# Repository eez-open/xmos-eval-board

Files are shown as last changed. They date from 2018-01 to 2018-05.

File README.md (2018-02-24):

### Ownership and License

The contributors are listed in CONTRIB.TXT. This project uses the TAPR v1.0 license, see LICENSE.TXT.
EEZ _xmos-eval-board_ uses the [C4.1 (Collective Code Construction Contract)](http://rfc.zeromq.org/spec:22) process for contributions.
To report an issue, use the [issue tracker](https://github.com/eez-open/xmos-eval-board/issues).

### Overview

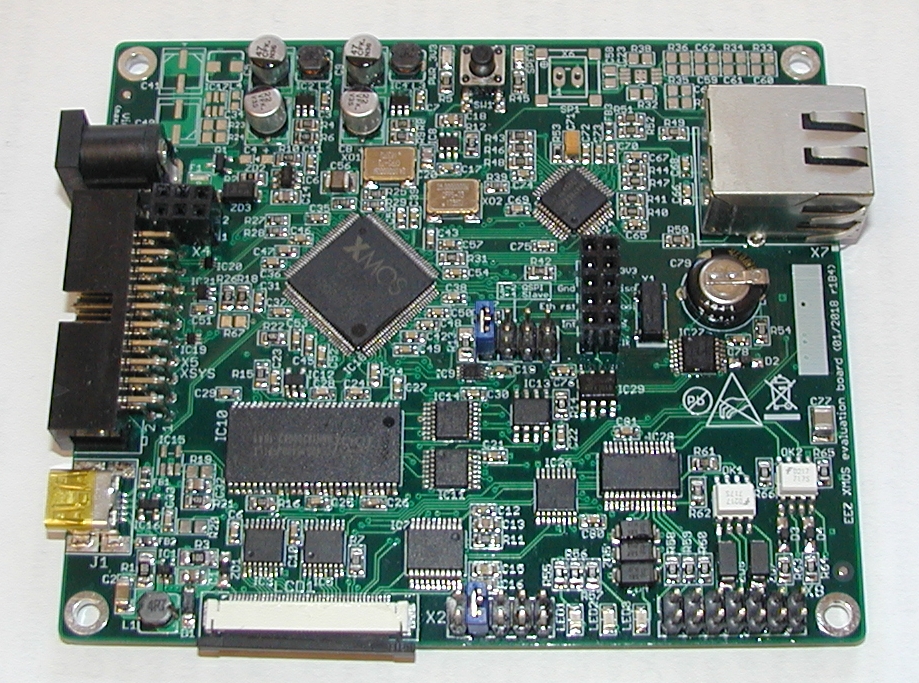
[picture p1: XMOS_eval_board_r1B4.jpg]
PCB r1B4 assembled


This project is an attempt to learn more about [XMOS xCORE-200](http://www.xmos.com/products/silicon/xcore-200) multicore microcontroller XE216-512-TQ128 by making evaluation board that would be used as a prototype or building block in some future DIY open source Test & Measurement (T&M) projects.
Selected MCU has 16 _logical_ cores divided between two hardware cores (_tiles_)and include USB 2.0 and [RGMII](https://en.wikipedia.org/wiki/Media-independent_interface) for Gigabit Ethernet. It has the highest pin count that comes in easy to mounting package (not BGA).
The evaluation board is based on XMOS evaluation boards and a couple of so-called _sliceCARDs_.

Evaluation board features:

- PCB dimension: 100 x 85 mm
- Power supply: 12 Vdc with on board regulators for 1 V, 3.3 V (sequenced) and 5 V (for USB host)
- XSYS 20-pin IDC connector for JTAG and real-time debugging (via 2-wire _xlink0_) with ESD protection
- USB AB-mini 5-pin plug with ESD protection (hopefully can be used for [OTG](https://en.wikipedia.org/wiki/USB_On-The-Go) operation)
- Support for RGB 4.3" LCD TFT (40-pin FFC 0.5 mm), 16-bit color space supported
- LCD WLED power supply with brightness control (PWM)
- Resistive touch screen controller (SPI)
- QSPI Flash memory
- 10-pin IDC connector for direct access to Flash memory
- 16-bit I/O port expander with 2 opto-isolated input, 2 opto-isolated outputs, 3 on-board LEDs, 3 TVS protected inputs
- Real time clock (SPI) with supercap backup (Vbat)
- EEPROM (SPI)
- SDRAM (multiplexed address and data bus)
- 20-pin FFC 0.5 mm socket for Riverdi LCD TFT displays (SPI, Audio out)
- Micro SD Card socket (SPI)
- 10/100 Mbit Ethernet PHY with RJ-45 socket
- Low-power audio amplifier
- 10-pin header for cheap W5500 Ethernet module (SPI)
- Reset switch

For MCU pin mapping check _[Portmap for EEZ evaluation board](XE216-512-TQ128_portmap_for_EEZ_evaluation_board_r1B4.pdf)_

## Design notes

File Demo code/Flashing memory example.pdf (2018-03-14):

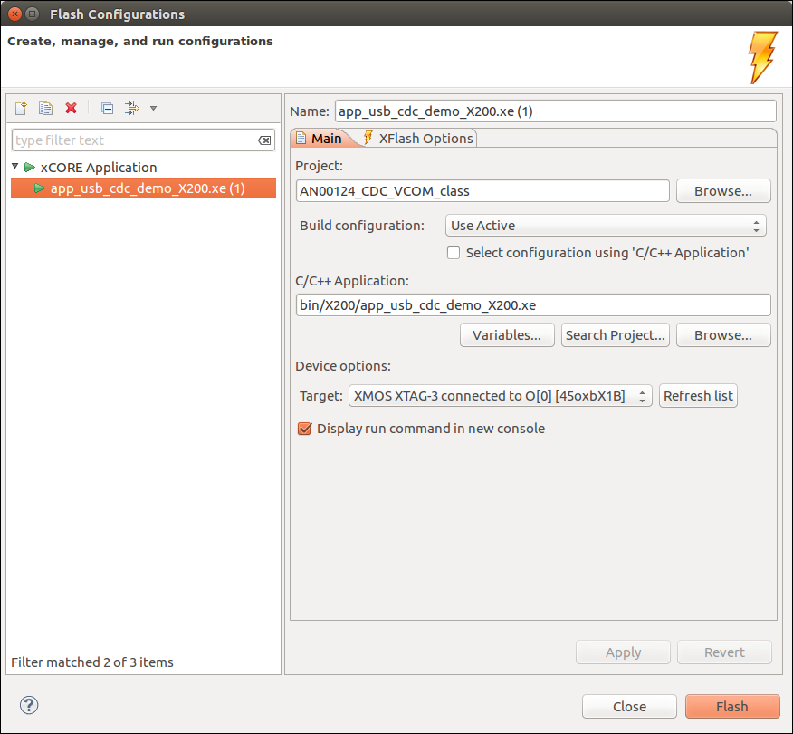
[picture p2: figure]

Adesto_AT25SF081.txt file content:

8, | /* 1. libflash device ID */
256, | /* 2. Page size */
2048, | /* 3. Number of pages */
3, | /* 4. Address size */
3, | /* 5. Clock divider */
0x9f, | /* 6. RDID cmd */
0, | /* 7. RDID dummy bytes */
3, | /* 8. RDID data size in bytes */
0x1F8501, | /* 9. RDID manufacturer ID */
0x20, | /* 10. SE cmd 0x20 */
4096, | /* 11. SE full sector erase */
0x06, | /* 12. WREN cmd 0x06 */
0x04, | /* 13. WRDI cmd 0x04 */
PROT_TYPE_SR, | /* 14. Protection type */
{{0x0 ,0x0 },{0,0}}, | /* 15. SR protect and unprotect cmds */
0x02, | /* 16. PP cmd */
0xeb, | /* 17. READ cmd */
1, | /* 18. READ dummy bytes */
SECTOR_LAYOUT_REGULAR, /* 19. Sector layout */
{4096,{0,{0}}}, | /* 20. Sector sizes */
0x05, | /* 21. RDSR cmd */
0x01, | /* 22. WRSR cmd 0x01 */
0x01, | /* 23. WIP bit mask */

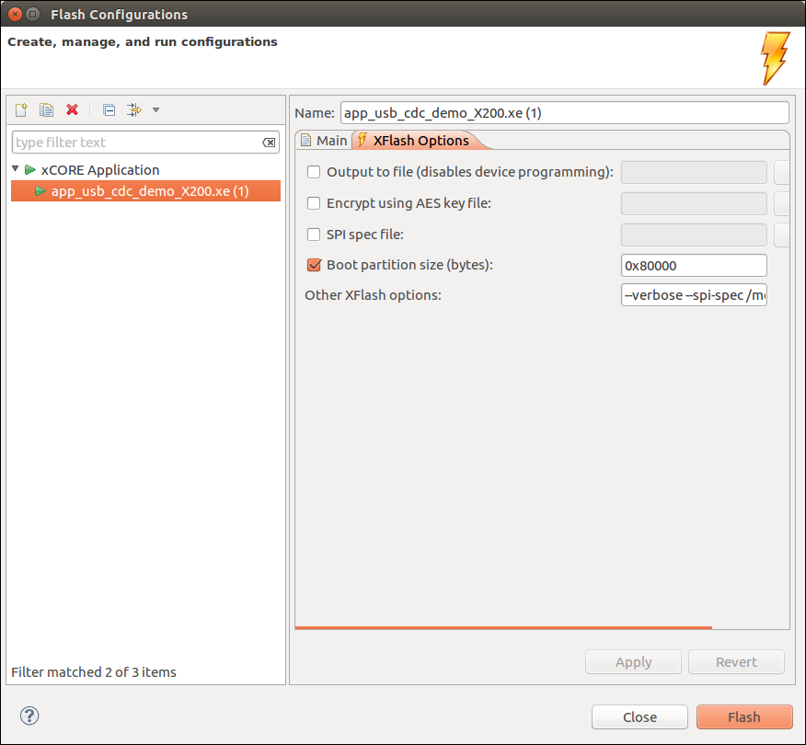
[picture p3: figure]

Other Xflash options:

--verbose --spi-spec
/media/denis/SSD_256GB/BACKUP/EEZ/XMOS/Community_14.3.2/bin/Adesto_AT25SF081.txt Flash operation results displayed in xTIMEcomposer console:

XFlash_Application found _start :40000 on Node 0
XFlash_Application found _DoSyscall :431c8 on Node 0 XFlash_Application found _DoException :400a4 on Node 0 XFlash_Application found _start :40000 on Node 0 XFlash_Application found _DoSyscall :40514 on Node 0 XFlash_Application found _DoException :400a4 on Node 0 XFlash_Application : Attempting to Compress Binary Data libcompressor marker 1=186
libcompressor marker 2=83
libcompressor marker 3=158
libcompressor best marker length 3 2 2 libcompressor best marker length 3 2 3 libcompressor best marker length 3 2 4 libcompressor best marker length 4 2 4 libcompressor best marker length 5 2 4
libcompressor best marker length 6 2 4
libcompressor DoCompression_Compress took : 216ms
libcompressor compile command=xcc -nostartfiles -Xmapper --bootstyle=forsim -x assembler-with-cpp "decompressor-3896629b" -x xn "target-xn-v0-3d1c5a34" -o decompressor-7fe0cb76 libcompressor validating decompressor decompressor-7fe0cb76 libcompressor launching simulator decompressor-7fe0cb76 --disable-syscalls --max-cycles 100000000
libcompressor simulator starting @0x40000
libcompressor simulator terminate @0x7ff58
libcompressor decompressor validated
XFlash_Application on Node : 0 compressed from : 14812 bytes to : 10432 bytes (29.57%)
libcompressor marker 1=19
libcompressor marker 2=26
libcompressor marker 3=30
libcompressor best marker length 3 2 2 libcompressor best marker length 3 2 3 libcompressor best marker length 3 2 4 libcompressor best marker length 3 2 5
libcompressor best marker length 4 2 5
libcompressor DoCompression_Compress took : 5ms
libcompressor compile command=xcc -nostartfiles -Xmapper --bootstyle=forsim -x assembler-with-cpp "decompressor-2804bf4d" -x xn "target-xn-v0-3d1c5a34" -o decompressor-c6a96ed7
libcompressor validating decompressor decompressor-c6a96ed7
libcompressor launching simulator decompressor-c6a96ed7 --disable-syscalls --max-cycles 100000000
libcompressor simulator starting @0x40000
libcompressor simulator terminate @0x7ff5a
libcompressor decompressor validated
XFlash_Application on Node : 0 compressed from : 1568 bytes to : 1308 bytes (16.58%)
XFlash::DoXFlash
XFlash::DoImageProgramming
XFlash::GetDeviceInfo
XFlash_DeviceInfo::GetDeviceInfo_Hardware XFlash_DeviceInfo::GetDeviceInfo_Hardware_IssueCompileCommand : xcc -Xmapper --dontenablesodlinks -Xmapper --wnoXN -x xc "spiinfo-1a9eb841" -x xn "target-xn-v0-3d1c5a34" -o "spiinfo-4bfe5879" -lquadflash -D xnPORT_SQI_CS0=PORT_SQI_CS -D xnPORT_SQI_SCLK0=PORT_SQI_SCLK -D xnPORT_SQI_SIO0=PORT_SQI_SIO XFlash_Utils::BuildRunCommand : xrun --io --adapter-id 45oxbX1B spiinfo-4bfe5879 Warning: F03098 XFlash::BuildFlashBinaryFile XFlash_Builder_S2L::BuildStage2Loaders Factory
Stage2_Loader::Compile : xcc -Wno-bidirectional-buffered-port -Xmapper --dontenablesodlinks -Xmapper --nochaninit -Xmapper --noinitialtidy -Xmapper --image-base -Xmapper 0x40080 -Xmapper --image-size -Xmapper 0x3ff80 -Xmapper --wno110 -Xmapper --wno226 -Xmapper --wnoXN -std=c99 -O2 -x xn "target-xn-v0-3d1c5a34" -x xc s2l-n0-cfcfc795 -lstage2loader -lswitchsetup -lsqiaccess -lquadspi -o s2l-n0-039e7cd5
Factory image and boot loader cannot be write-protected on flash device on node 0
xflash: Warning: F03148 --quad-spi-clock not given, using default 15.62MHz Stage2Loader found _DoSyscall : 0x404c8 on Node 0
Stage2Loader found _DoException : 0x40124 on Node 0
Stage2_Loader : Attempting to Compress Binary Data
libcompressor marker 1=123
libcompressor marker 2=125
libcompressor marker 3=163
libcompressor best marker length 3 2 2 libcompressor best marker length 3 2 3 libcompressor best marker length 3 2 4 libcompressor best marker length 4 2 4 libcompressor best marker length 4 2 5 libcompressor DoCompression_Compress took : 26ms libcompressor compile command=xcc -nostartfiles -Xmapper --bootstyle=forsim -x assembler-with-cpp "decompressor-202ebb54" -x xn "target-xn-v0-3d1c5a34" -o decompressor-45c8dd14
libcompressor validating decompressor decompressor-45c8dd14
libcompressor launching simulator decompressor-45c8dd14 --disable-syscalls --max-cycles 100000000
libcompressor simulator starting @0x40000
libcompressor simulator terminate @0x7feda
libcompressor decompressor validated
Stage2_Loader on Node : 0 compressed from : 4872 bytes to : 3804 bytes (21.92%) Stage2_SwitchSetup::Compile : xcc -c -march=xs2a -x assembler-with-cpp swstup-n0v0-2e7eb038 -o swstup-n0v0-90eef87c
Stage2_SwitchSetup::Compile : xcc -nostartfiles -Wno-bidirectional-buffered-port -Xmapper --first -Xmapper swstup-n0v0-90eef87c -Xmapper --dontenablesodlinks -Xmapper --nochaninit -Xmapper --noinitialtidy -Xmapper --wno110 -Xmapper --wno226 -Xmapper --wnoXN -std=c99 -O2 -x xn "target-xn-v0-3d1c5a34" -x xc swstup-n0v0-6487ad4c -lswitchsetup -o swstup-n0v0-e168c184 XFlash_Builder_Image::BuildImages Factory XFlash_Builder_Image::BuildImageTable
master node = 0
node = 0
XFlash_Builder_Image::BuildImageTable num cores for image table = 2 XFlash_Builder_Image::CalculateBufferSize Starting calculation _total_image_size=0
XFlash_Builder_Image::CalculateBufferSize Add Image Header _total_image_size=34 XFlash_Builder_Image::CalculateBufferSize Add Switch Setup header _total_image_size=3c
XFlash_Builder_Image::CalculateBufferSize Add Per Core header _total_image_size=54
XFlash_Builder_Image::CalculateBufferSize_SwitchSetup _total_image_size=7ac XFlash_Builder_Image::CalculateBufferSize_Application application size = 28c4 _total_image_size = 3070
XFlash_Builder_Image::CalculateBufferSize_Application application size = 520 _total_image_size = 3590
XFlash_Builder_Image::BuildImageTable allocated image buffer size = 3590 XFlash_Builder_Image::WriteBuffer_ImageHeader XFlash_Builder_Image::WriteBuffer_SwitchSetup current switch setup table offset : 34
XFlash_Builder_Image::WriteBuffer_SwitchSetup current application data offset : 54
XFlash_Builder_Image::WriteBuffer_SwitchSetup size : 754 XFlash_Builder_Image::WriteBuffer_SwitchSetup aligned_size : 758 XFlash_Builder_Image::WriteBuffer_SwitchSetup init_vec_shift : 0 XFlash_Builder_Image::WriteBuffer_Application XFlash_Builder_Image::WriteBuffer_Application for node : 0 XFlash_Builder_Image::WriteBuffer_Application for core : 0 XFlash_Builder_Image::WriteBuffer_Application current core table offset : 3c XFlash_Builder_Image::WriteBuffer_Application current application data offset : 7ac
XFlash_Builder_Image::WriteBuffer_Application size : 28c0 XFlash_Builder_Image::WriteBuffer_Application aligned_size : 28c4 XFlash_Builder_Image::WriteBuffer_Application init_vec_shift : 0 XFlash_Builder_Image::WriteBuffer_Application chan end : 80020002 XFlash_Builder_Image::WriteBuffer_Application for core : 1 XFlash_Builder_Image::WriteBuffer_Application current core table offset : 48 XFlash_Builder_Image::WriteBuffer_Application current application data offset : 3070
XFlash_Builder_Image::WriteBuffer_Application size : 51c XFlash_Builder_Image::WriteBuffer_Application aligned_size : 520 XFlash_Builder_Image::WriteBuffer_Application init_vec_shift : 0 XFlash_Builder_Image::WriteBuffer_Application chan end : 80030002 XFlash_Builder_Image::WriteBuffer_CRC

XFlash_Builder_Binary::BuildBinary XFlash_Builder_Binary::CalculateBufferSize_Factory XFlash_Builder_Binary::CalculateBufferSize_Factory : Adding s2l size word (4)4 XFlash_Builder_Binary::CalculateBufferSize_Factory : Adding s2l app (f5c) f60 XFlash_Builder_Binary::CalculateBufferSize_Factory : Adding s2l crc (4)f64 XFlash_Builder_Binary::CalculateBufferSize_Factory : Adding factory app (3590) 44f4
XFlash_Builder_Binary::CalculateBufferSize_Factory : Adding sector padding (b0c) 5000
XFlash_Builder_Binary::CalculateBufferSize_Factory : First User Sector offset = 5000
XFlash_Builder_Binary::GetSearchLimitPadding : current size (5000) 0 XFlash_Builder_Binary::CalculateBufferSize_Data XFlash_Builder_Binary::BuildBinary : Allocating buffer - 5000 XFlash_Builder_Binary::GetSearchLimitPadding : current size (5000) 0 XFlash_Builder_Binary::WriteBufferToBinary : flash_bin_node0 XFlash_Programmer_Program::DoProgram XFlash_Programmer_Program::GenerateSource XFlash_Programmer_Program::IssueCompileCommand :xcc -w -Xmapper --dontenablesodlinks -O2 -lquadflash -x xc "fp-74d548f5" -x xn "target-xn-v0-3d1c5a34" -D VERBOSE=1 -D MONITOR=1 -D ERASE_ALL_FIRST=1 -o "fp-b36c12d3" XFlash_Utils::BuildRunCommand : xrun --io --adapter-id 45oxbX1B fp-b36c12d3

Site 0 has started.
Site 0 has type 008.
Site 0 write 0x00000000.
Site 0 verified 0x00000000. Site 0 write 0x00000100.
Site 0 verified 0x00000100. Site 0 write 0x00000200.
Site 0 verified 0x00000200. Site 0 write 0x00000300.
Site 0 verified 0x00000300. Site 0 write 0x00000400.
Site 0 verified 0x00000400. Site 0 write 0x00000500.
Site 0 verified 0x00000500. Site 0 write 0x00000600.
Site 0 verified 0x00000600. Site 0 write 0x00000700.
Site 0 verified 0x00000700. Site 0 write 0x00000800.
Site 0 verified 0x00000800. Site 0 write 0x00000900.
Site 0 verified 0x00000900. Site 0 write 0x00000a00.
Site 0 verified 0x00000a00. Site 0 write 0x00000b00.
Site 0 verified 0x00000b00. Site 0 write 0x00000c00.
Site 0 verified 0x00000c00. Site 0 write 0x00000d00.
Site 0 verified 0x00000d00. Site 0 write 0x00000e00.
Site 0 verified 0x00000e00. Site 0 write 0x00000f00.
Site 0 verified 0x00000f00. Site 0 write 0x00001000.
Site 0 verified 0x00001000. Site 0 write 0x00001100.
Site 0 verified 0x00001100. Site 0 write 0x00001200.

Site 0 verified 0x00001200. Site 0 write 0x00001300.
Site 0 verified 0x00001300. Site 0 write 0x00001400.
Site 0 verified 0x00001400. Site 0 write 0x00001500.
Site 0 verified 0x00001500. Site 0 write 0x00001600.
Site 0 verified 0x00001600. Site 0 write 0x00001700.
Site 0 verified 0x00001700. Site 0 write 0x00001800.
Site 0 verified 0x00001800. Site 0 write 0x00001900.
Site 0 verified 0x00001900. Site 0 write 0x00001a00.
Site 0 verified 0x00001a00. Site 0 write 0x00001b00.
Site 0 verified 0x00001b00. Site 0 write 0x00001c00.
Site 0 verified 0x00001c00. Site 0 write 0x00001d00.
Site 0 verified 0x00001d00. Site 0 write 0x00001e00.
Site 0 verified 0x00001e00. Site 0 write 0x00001f00.
Site 0 verified 0x00001f00. Site 0 write 0x00002000.
Site 0 verified 0x00002000. Site 0 write 0x00002100.
Site 0 verified 0x00002100. Site 0 write 0x00002200.
Site 0 verified 0x00002200. Site 0 write 0x00002300.
Site 0 verified 0x00002300. Site 0 write 0x00002400.
Site 0 verified 0x00002400. Site 0 write 0x00002500.
Site 0 verified 0x00002500. Site 0 write 0x00002600.
Site 0 verified 0x00002600. Site 0 write 0x00002700.
Site 0 verified 0x00002700. Site 0 write 0x00002800.
Site 0 verified 0x00002800. Site 0 write 0x00002900.
Site 0 verified 0x00002900. Site 0 write 0x00002a00.
Site 0 verified 0x00002a00. Site 0 write 0x00002b00.
Site 0 verified 0x00002b00. Site 0 write 0x00002c00.
Site 0 verified 0x00002c00. Site 0 write 0x00002d00.
Site 0 verified 0x00002d00. Site 0 write 0x00002e00.
Site 0 verified 0x00002e00. Site 0 write 0x00002f00.
Site 0 verified 0x00002f00. Site 0 write 0x00003000.
Site 0 verified 0x00003000. Site 0 write 0x00003100.

Site 0 verified 0x00003100. Site 0 write 0x00003200.
Site 0 verified 0x00003200. Site 0 write 0x00003300.
Site 0 verified 0x00003300. Site 0 write 0x00003400.
Site 0 verified 0x00003400. Site 0 write 0x00003500.
Site 0 verified 0x00003500. Site 0 write 0x00003600.
Site 0 verified 0x00003600. Site 0 write 0x00003700.
Site 0 verified 0x00003700. Site 0 write 0x00003800.
Site 0 verified 0x00003800. Site 0 write 0x00003900.
Site 0 verified 0x00003900. Site 0 write 0x00003a00.
Site 0 verified 0x00003a00. Site 0 write 0x00003b00.
Site 0 verified 0x00003b00. Site 0 write 0x00003c00.
Site 0 verified 0x00003c00. Site 0 write 0x00003d00.
Site 0 verified 0x00003d00. Site 0 write 0x00003e00.
Site 0 verified 0x00003e00. Site 0 write 0x00003f00.
Site 0 verified 0x00003f00. Site 0 write 0x00004000.
Site 0 verified 0x00004000. Site 0 write 0x00004100.
Site 0 verified 0x00004100. Site 0 write 0x00004200.
Site 0 verified 0x00004200. Site 0 write 0x00004300.
Site 0 verified 0x00004300. Site 0 write 0x00004400.
Site 0 verified 0x00004400. Site 0 write 0x00004500.
Site 0 verified 0x00004500. Site 0 write 0x00004600.
Site 0 verified 0x00004600. Site 0 write 0x00004700.
Site 0 verified 0x00004700. Site 0 write 0x00004800.
Site 0 verified 0x00004800. Site 0 write 0x00004900.
Site 0 verified 0x00004900. Site 0 write 0x00004a00.
Site 0 verified 0x00004a00. Site 0 write 0x00004b00.
Site 0 verified 0x00004b00. Site 0 write 0x00004c00.
Site 0 verified 0x00004c00. Site 0 write 0x00004d00.
Site 0 verified 0x00004d00. Site 0 write 0x00004e00.
Site 0 verified 0x00004e00.
Site 0 write 0x00004f00.
Site 0 verified 0x00004f00.
Site 0 has finished successfully.

XFlash_Programmer_Program::IssueResetCommand : xgdb --batch-silent --ex connect --adapter-id 45oxbX1B --ex reset mode-pins nointerrupt --ex q

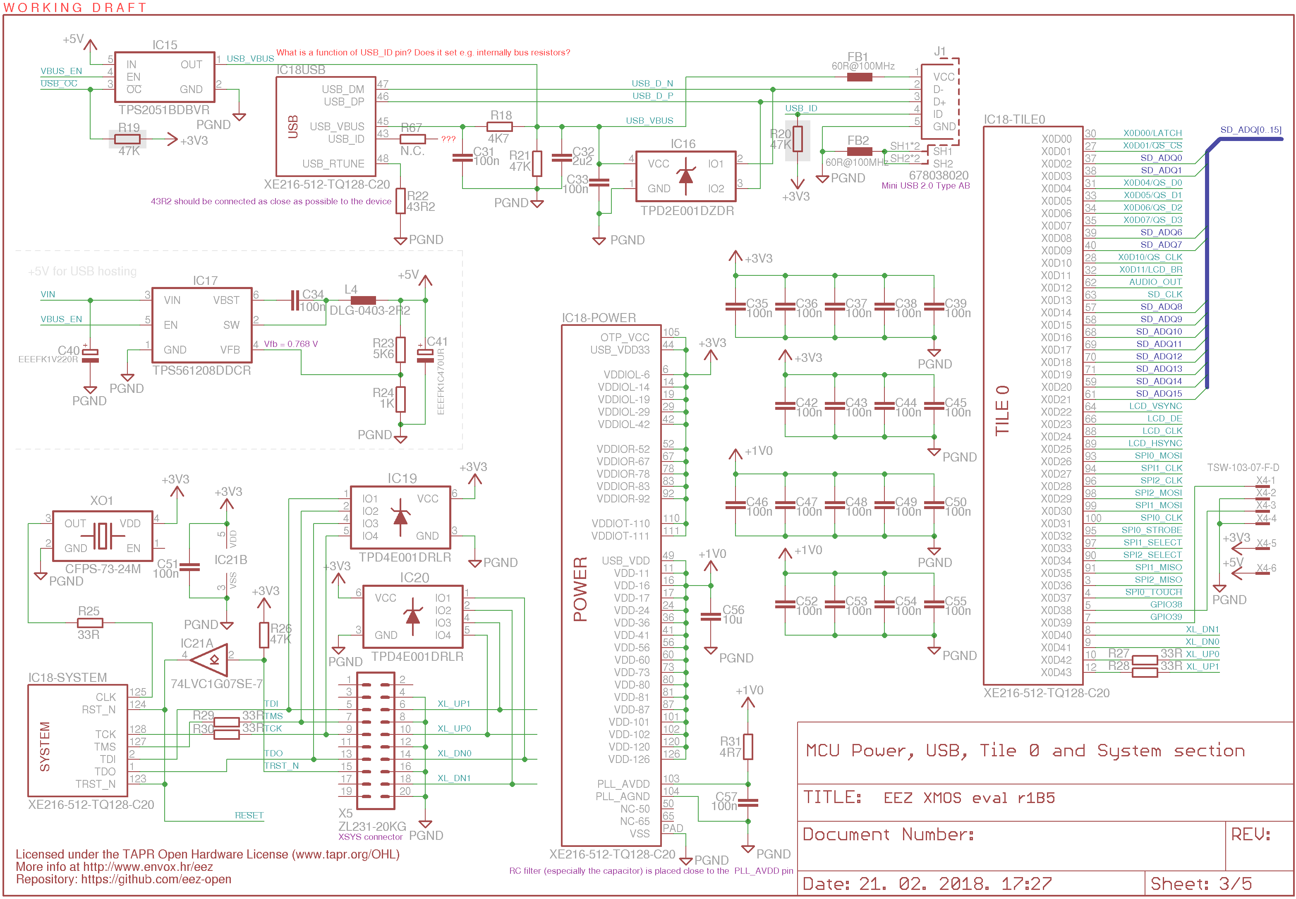
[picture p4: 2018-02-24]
EEZ XMOS eval r1B5 Sheet 3of5.png

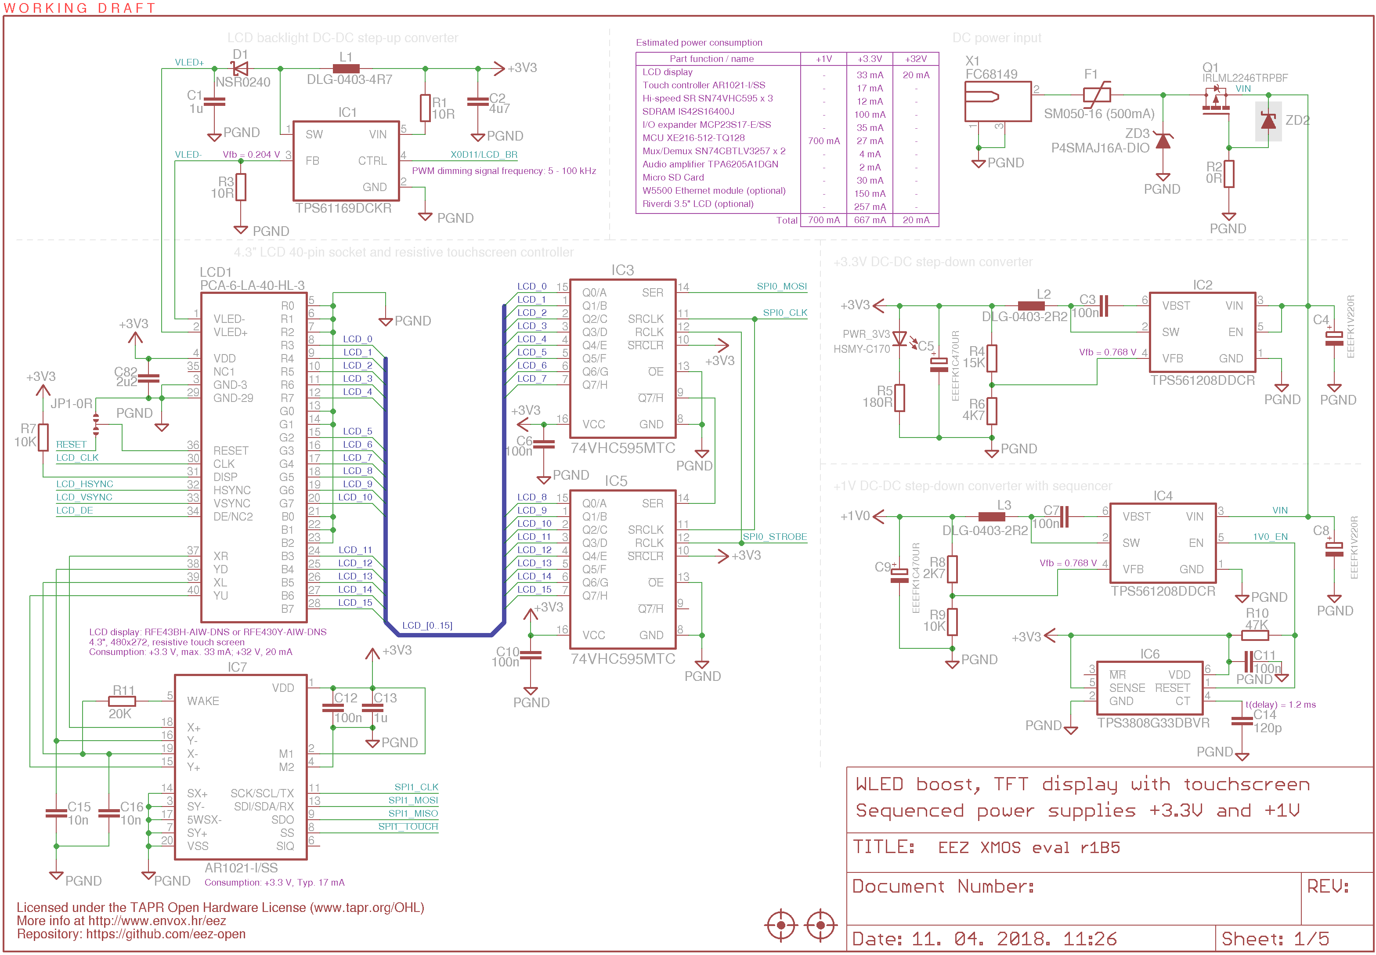
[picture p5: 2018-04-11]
EEZ XMOS eval r1B5 Sheet 1of5.png

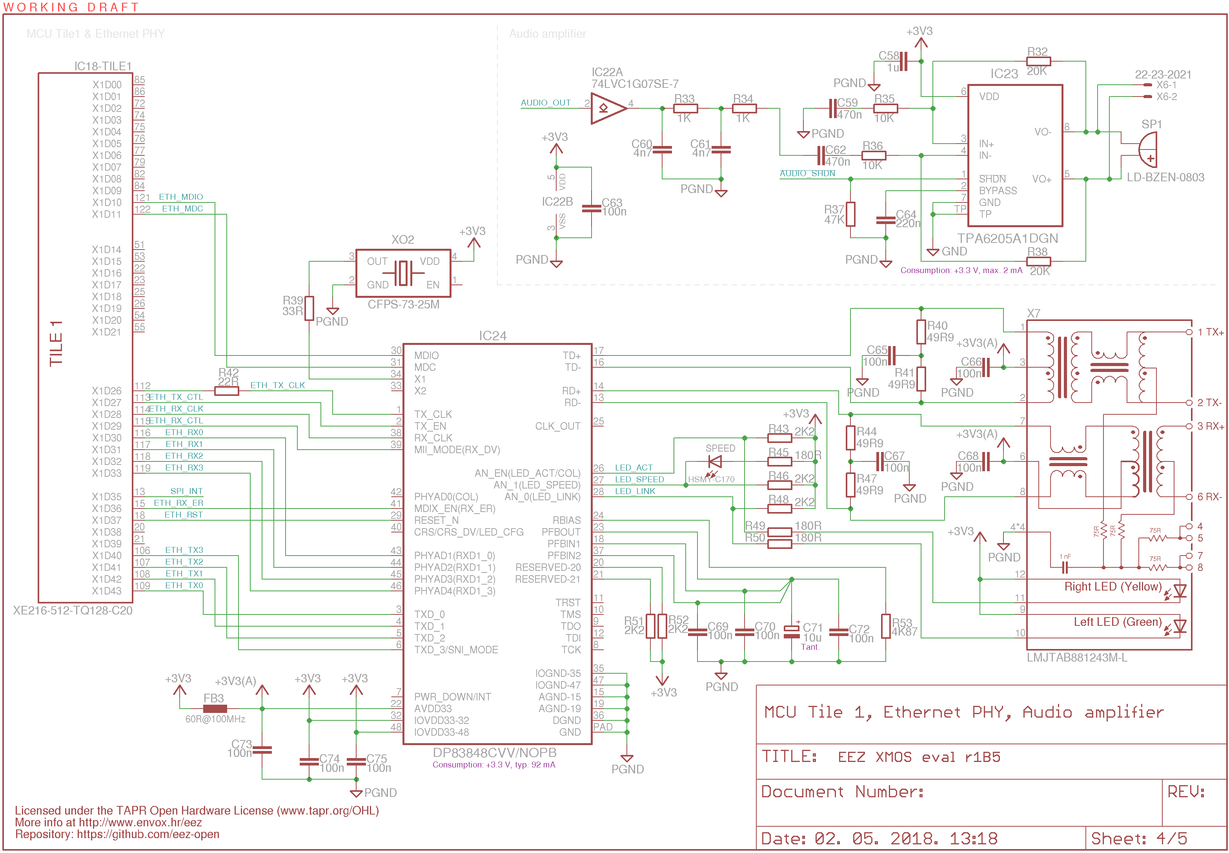
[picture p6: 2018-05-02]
EEZ XMOS eval r1B5 Sheet 4of5.png

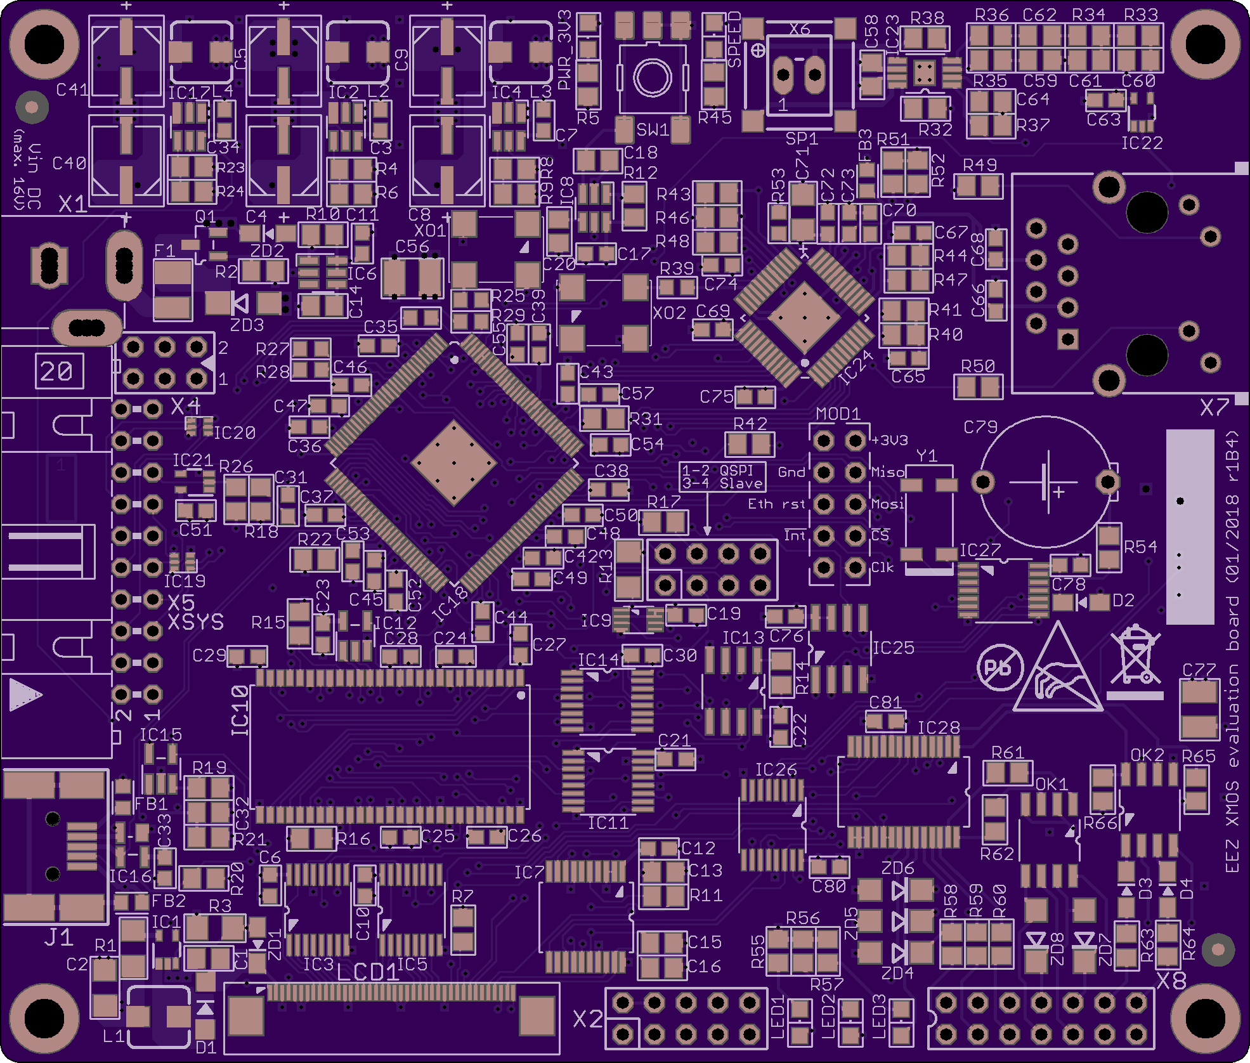
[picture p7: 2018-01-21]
EEZ_XMOS_eval_preview.png

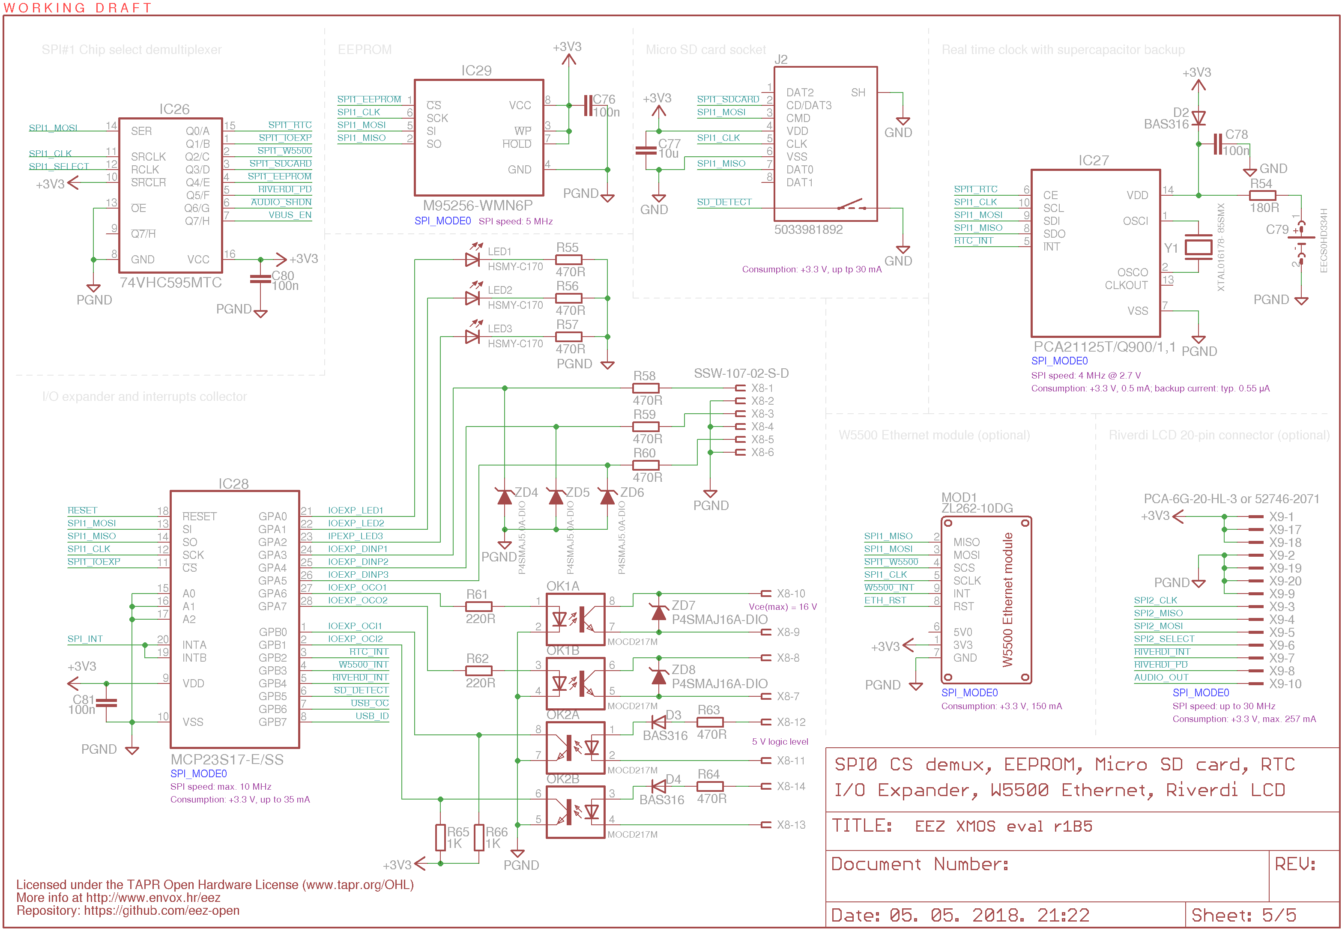
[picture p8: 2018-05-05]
EEZ XMOS eval r1B5 Sheet 5of5.png

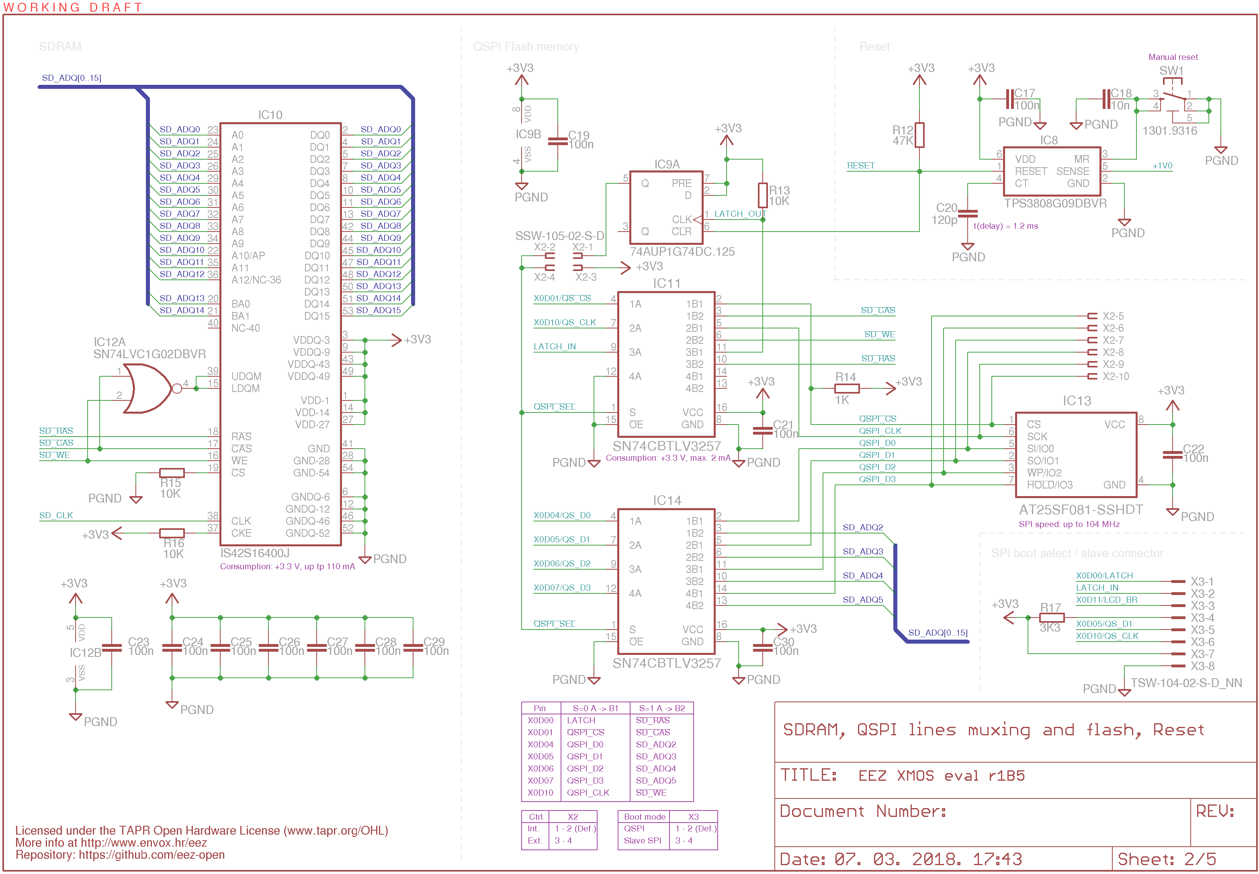
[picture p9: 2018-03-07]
EEZ XMOS eval r1B5 Sheet 2of5.png

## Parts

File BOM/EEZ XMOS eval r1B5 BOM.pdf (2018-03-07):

EEZ XMOS evaluation board BOM (r1B5, 2018-03-07) Project source code at https://github.com/eez-open

Farnell / Element14 | Digi-Key
Qty | Part name | Package | Reference designator | Code | Part Number | Unit price € | MOQ | Part Number Unit price € | MOQ
1 | 3 1u | 0805 | C1, C13, C58
2 | 2 120p | 0805 | C14, C20
3 | 3 10n | 0805 | C15, C16, C18
4 | 1 4u7 | 1206 | C2
5 | 56 100n | 0603
6 | 2 2u2 | 0805 | C32, C82
7 | 3 EEEFK1V220R | 22uF 35VDC, 5x5.8mm | C4, C8, C40 | 9695834 | EEEFK1V220R | 0,241 € | 1
8 | 3 EEEFK1C470UR | 47uF 35VDC, 5x5.8mm | C5, C9, C41 | 9695664 | EEEFK1C470U | 0,241 € | 1
9 | 2 10u | 1210 | C56, C77
10 | 2 470n | 0805 | C59, C62
11 | 2 4n7 | 0805 | C60, C61
12 | 1 220n | 0805 | C64
13 | 1 10u | 1206 | C71
14 | 1 EECS0HD334H | Supercap 10mm | C79 | 1751930 | EECS0HD334H | 1,820 € | 1
15 | 1 NSR0240 | SOD123 | D1
16 | 3 BAS316 | SOD323 | D2, D3, D4
17 | 1 SM050-16 (500mA) | Fuse, 1210 | F1
18 | 3 60R@100MHz | Ferrite bead, 0603 | FB1, FB2, FB3
19 | 1 TPS61169DCKR | | IC1 | 2542731 | TPS61169DCKR | 0,917 € | 1
20 | 1 IS42S16400J | TSOP-II-54 | IC10 | 2253831 | IS42S16400J-7TLI | 1,950 € | 1
21 | 2 SN74CBTLV3257 | | IC11, IC14 | 1872789 | | 0,801 € | 1
22 | 1 SN74LVC1G02DBVR | | IC12 | 1287579 | SN74LVC1G02DBVR | 0,284 € | 5
23 | 1 AT25SF041-SSHDT | Serial flash, SOIC8 | IC13 | -
24 | 1 TPS2051BDBVR | | IC15 | 2296067 | TPS2051BDBVR | 1,180 € | 1
25 | 1 TPD2E001DZDR | | IC16 | 2335446 | TPD2E001DZDR | 0,506 € | 5
26 | 1 XE216-512-TQ128-C20 | | IC18 | 2499221 | | 17,670 € | 1
27 | 2 TPD4E001DRLR | | IC19, IC20 | 1611469 | TPD4E001DRLR | 0,570 € | 5
28 | 3 TPS561208DDCR | | IC2, IC4, IC17 | 2766883 | TPS561208DDCT | 1,010 € | 1
29 | 2 74LVC1G07SE-7 | SC70 | IC21, IC22 | 1845213 | 74LVC1G07SE-7 | 1,530 € | 1
30 | 1 TPA6205A1DGN | | IC23 | 1697151 | TPA6205A1DGN | 1,140 € | 1
31 | 1 DP83848CVV/NOPB | | IC24 | 1685784 | DP83848CVV/NOPB | 5,460 € | 1

C3, C6, C7, C10, C11, C12, C17, C19, C21, C22, C23, C24, C25, C26, C27, C28, C29, C30, C31, C33, C34, C35, C36, C37, C38, C39, C42, C43, C44, C45, C46, C47, C48, C49, C50, C51, C52, C53, C54, C55, C57, C63, C65, C66, C67, C68, C69, C70, C72, C73, C74, C75, C76, C78, C80, C81

SN74CBTLV3257PW
R

XE216-512-TQ128-
C20

32 | 1 M95256-WMN6P | SOIC8 | IC25 | 1099712 | M95256-WMN6P | 0,321 € | 1
33 | 1 PCA21125T/Q900/1,1 | TSSOP14 | IC27 | 2400445 | | 1,760 € | 1
34 | 1 MCP23S17-E/SS | | IC28 | 1467675 | MCP23S17-E/SS | 1,190 € | 1
35 | 3 74VHC595MTC | | IC3, IC5, IC26 | 2453164 | 74VHC595MT | 0,447 € | 5
36 | 1 TPS3808G33DBVR | | IC6 | 1703467 | TPS3808G33DBVR | 1,590 € | 1
37 | 1 AR1021-I/SS | | IC7 | 2218568 | AR1021-I/SS | 1,710 € | 1
38 | 1 TPS3808G09DBVR | | IC8 | 2764653 | TPS3808G09DBV | 1,930 € | 1
39 | 1 74AUP1G74DC.125 | | IC9 | 2445023 | 74AUP1G74DC.125 | 0,424 € | 5
40 | 1 678038020 | USB AB mini socket | J1
41 | 1 5033981892 | SD Micro; push-push | J2
42 | 1 DLG-0403-4R7 | Inductor 4.7uH, 0403 | L1
43 | 3 DLG-0403-2R2 | Inductor 2.2uH, 0403 | L2, L3, L4
44 | 1 PCA-6-LA-40-HL-3 | | LCD1
45 | 5 HSMY-C170 | LED0805
46 | 2 MOCD217M | | OK1, OK2
47 | 1 IRLML2246TRPBF | | Q1
48 | 2 10R | 1206 | R1, R3
49 | 7 47K | 0805 | R10, R12, R19, R20, R21, R26, R37
50 | 3 20K | 0805 | R11, R32, R38
51 | 1 3K3 | 0805 | R17
52 | 1 4K7 | 0805 | R18
53 | 3 0R | 0805 | R2, R67, JP1
54 | 1 43R2 | 0805 | R22
55 | 1 56K | 0805 | R23
56 | 6 33R | 0603 | R25, R27, R28, R29, R30, R39
57 | 2 4R7 | 0805 | R6, R31
58 | 4 1K | 0805 | R33, R34, R65, R66
59 | 1 15K | 0805 | R4
60 | 4 49R9 | 0805 | R40, R41, R44, R47
61 | 1 22R | 0805 | R42
62 | 5 2K2 | 0805 | R43, R46, R48, R51, R52
63 | 5 180R | 0805 | R5, R45, R49, R50, R54
64 | 1 4K87 | 0603 | R53
65 | 8 470R | 0805
66 | 9 10K | 0805
67 | 2 220R | 0805 | R61, R62
68 | 1 2K7 | 0805 | R8
69 | 1 LD-BZEN-0803 | Buzzer | SP1
70 | 1 1301.9316 | Reset switch | SW1
71 | 1 FC68149 | DC input plug, 5,5/2,5mm | X1

PCA21125T/Q900/1,
1

FFC horizontal, 40-pin bottom contacts
LED1, LED2, LED3, PWR_3V3, SPEED

R55, R56, R57, R58, R59, R60, R63, R64
R7, R9, R13, R14, R15, R16, R24, R35, R36

72 | 1 SSW-105-02-S-D | | X2
73 | 1 TSW-104-02-S-D_NN | | X3
74 | 1 TSW-103-07-F-D | | X4
75 | 1 ZL231-20KG | 20-pin IDC right angle | X5
76 | 1 22-23-2021 | | X6
77 | 1 LMJTAB881243M-L | RJ45 Ethernet jack | X7
78 | 1 SSW-107-02-S-D | | X8
79 | 1 CFPS-73-24M | Xtal oscillator | XO1
80 | 1 CFPS-73-25M | Xtal oscillator | XO2
81 | 1 XTAL016178- 85SMX | RTC xtal | Y1
82 | 3 P4SMAJ16A-DIO | | ZD3, ZD7, ZD8
83 | 3 P4SMAJ5.0A-DIO | | ZD4, ZD5, ZD6
84 1 Option #1: RFE43BH-AIW-DNS
| Option #2: RFE430Y-AIW-DNS

Optional / not installed
1 ZL262-10DG | ETH_W5500_MODULE | MOD1
1 PCA-6G-20-HL-3 or 52746-207 | | X9
1 ??? | SOD323 | ZD2

4.3” 480x272 LCD with resistive touch screen
4.3” 480x272 LCD with resistive touch screen

FFC horizontal, 20-pin bottom contacts

Mouser | RS Components | TME | Price calculation for 1 set
| | Code / Part Number
Part Number Unit price € | MOQ | Code | Part Number Unit price € | MOQ | Unit price € MOQ | THT SMD | Order Qty | Line Cost €
3 | Farnell | 0,000 € | 1 | 0,000 €
2 | Farnell | 0,000 € | 1 | 0,000 €
3 | Farnell | 0,000 € | 1 | 0,000 €
1 | Farnell | 0,000 € | 1 | 0,000 €
56 | Farnell | 0,000 € | 1 | 0,000 €
| | | | 2 | Farnell | 0,000 € | 1 | 0,000 €
EEEFK1V220R | 0,126 € | 5 | | 3 | TME | 0,126 € | 1 | 0,126 €
EEEFK1C470UR | 0,173 € | 5 | | 3 | TME | 0,173 € | 1 | 0,173 €
| | | | 2 | Farnell | 0,000 € | 1 | 0,000 €
| | | | 2 | Farnell | 0,000 € | 1 | 0,000 €
| | | | 2 | Farnell | 0,000 € | 1 | 0,000 €
| | | | 1 | Farnell | 0,000 € | 1 | 0,000 €
| | | | 1 | Farnell | 0,000 € | 1 | 0,000 €
EECS0HD334H | 0,950 € | 1 | 1 | 1 | TME | 0,950 € | 1 | 0,950 €
| | | | 1 | Farnell | 0,000 € | 1 | 0,000 €
| | | | 3 | Farnell | 0,000 € | 1 | 0,000 €
SM050-16 | 0,080 € 10 | 1 | TME | 0,080 € | 1 | 0,080 €
LCBA-600 | 0,025 € 25 | 3 | TME | 0,025 € | 1 | 0,025 €
| | | | 1 | Farnell | 0,917 € | 1 | 0,917 €
IS42S16400J-7TLI | 3,150 € | 1 | | 1 | Farnell | 1,950 € | 1 | 1,950 €
| | | | 2 | Farnell | 0,801 € | 1 | 0,801 €
| | | | 1 | Farnell | 0,284 € | 1 | 0,284 €
| 0,400 € | 3 | | 1 | TME | 0,400 € | 1 | 0,400 €
| | | | 1 | Farnell | 1,180 € | 1 | 1,180 €
| | | | 1 | Farnell | 0,506 € | 1 | 0,506 €
| | | | 1 | Farnell | 17,670 € | 1 | 17,670 €
| | | | 2 | Farnell | 0,570 € | 1 | 0,570 €
| | | | 3 | Farnell | 1,010 € | 1 | 1,010 €
74LVC1G07SE-7 | 0,048 € 10 | 2 | TME | 0,048 € | 1 | 0,048 €
| | | | 1 | Farnell | 1,140 € | 1 | 1,140 €
| | | | 1 | Farnell | 5,460 € | 1 | 5,460 €

Best
Supplier

Lowest unit
price €

AT25SF081-
SSHDT

M95256-WMN6P | 0,550 € | 1 | 1 | Farnell | 0,321 € | 1 | 0,321 €
1 | Farnell | 1,760 € | 1 | 1,760 €
MCP23S17-E/SS | 1,130 € | 1 | 1 | TME | 1,130 € | 1 | 1,130 €
3 | Farnell | 0,447 € | 1 | 0,447 €
1 | Farnell | 1,590 € | 1 | 1,590 €
AR1021-I/SS | 2,060 € | 1 | 1 | Farnell | 1,710 € | 1 | 1,710 €
1 | Farnell | 1,930 € | 1 | 1,930 €
0,323 € | 3 | 1 | TME | 0,323 € | 1 | 0,323 €
MX-67803-8020 | 0,610 € | 1 | 1 | TME | 0,610 € | 1 | 0,610 €
MX-503398-1892 | 1,430 € | 1 | 1 | TME | 1,430 € | 1 | 1,430 €
DLG-0403-4R7 | 0,122 € 10 | 1 | TME | 0,122 € | 1 | 0,122 €
DLG-0403-2R2 | 0,122 € 10 | 3 | TME | 0,122 € | 1 | 0,122 €
PCA-6-LA-40-HL-3 | 0,650 € | 1 | TME | 0,650 € | 1 | 0,650 €
5 | Farnell | 0,000 € | 1 | 0,000 €
2 | Farnell | 0,000 € | 1 | 0,000 €
IRLML2246TRPBF | 0,115 € | 5 | 1 | TME | 0,115 € | 1 | 0,115 €
2 | Farnell | 0,000 € | 1 | 0,000 €
7 | Farnell | 0,000 € | 1 | 0,000 €
3 | Farnell | 0,000 € | 1 | 0,000 €
1 | Farnell | 0,000 € | 1 | 0,000 €
1 | Farnell | 0,000 € | 1 | 0,000 €
3 | Farnell | 0,000 € | 1 | 0,000 €
1 | Farnell | 0,000 € | 1 | 0,000 €
1 | Farnell | 0,000 € | 1 | 0,000 €
6 | Farnell | 0,000 € | 1 | 0,000 €
2 | Farnell | 0,000 € | 1 | 0,000 €
4 | Farnell | 0,000 € | 1 | 0,000 €
1 | Farnell | 0,000 € | 1 | 0,000 €
4 | Farnell | 0,000 € | 1 | 0,000 €
1 | Farnell | 0,000 € | 1 | 0,000 €
5 | Farnell | 0,000 € | 1 | 0,000 €
5 | Farnell | 0,000 € | 1 | 0,000 €
1 | Farnell | 0,000 € | 1 | 0,000 €
8 | Farnell | 0,000 € | 1 | 0,000 €
9 | Farnell | 0,000 € | 1 | 0,000 €
2 | Farnell | 0,000 € | 1 | 0,000 €
1 | Farnell | 0,000 € | 1 | 0,000 €
LD-BZEN-0803 | 0,696 € 10 | 1 | TME | 0,696 € | 1 | 0,696 €
1301.9316 | 0,230 € 10 | 1 | 1 | TME | 0,230 € | 1 | 0,230 €
FC68149 | 0,521 € | 1 | 1 | TME | 0,521 € | 1 | 0,521 €

74AUP1G74DC.12
5

1 | Farnell | 0,000 € | 1 | 0,000 €
1 | Farnell | 0,000 € | 1 | 0,000 €
1 | Farnell | 0,000 € | 1 | 0,000 €
ZL231-20KG | 0,271 € | 2 | 1 | TME | 0,271 € | 1 | 0,271 €
1 | Farnell | 0,000 € | 1 | 0,000 €
3,170 € | 1 | 1 | TME | 3,170 € | 1 | 3,170 €
1 | Farnell | 0,000 € | 1 | 0,000 €
CFPS-73-24M | 2,460 € | 1 | 1 | TME | 2,460 € | 1 | 2,460 €
CFPS-73-25M | 2,460 € | 1 | 1 | TME | 2,460 € | 1 | 2,460 €
1 | Farnell | 0,000 € | 1 | 0,000 €
3 | Farnell | 0,000 € | 1 | 0,000 €
3 | Farnell | 0,000 € | 1 | 0,000 €
24,810 € | 1 | - | - | TME | 24,810 € | 1 | 24,810 €
Total components 10 | 212 | Total | 80,168 €

LMJTAB881243M-L

RFE43BH-AIW-DNS
RFE430Y-AIW-DNS

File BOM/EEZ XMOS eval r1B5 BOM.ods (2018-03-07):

 |  |  |  |  | Farnell / Element14 |  |  |  | Digi-Key |  |  | Mouser |  |  | RS Components |  |  |  | TME |  |  |  |  | Price calculation for 1 set
# | Qty | Part name | Package | Reference designator | Code | Part Number | Unit price € | MOQ | Part Number | Unit price € | MOQ | Part Number | Unit price € | MOQ | Code | Part Number | Unit price € | MOQ | Code / Part Number | Unit price € | MOQ | THT | SMD | Best Supplier | Lowest unit price € | Order Qty | Line Cost €
1 | 3 | 1u | 0805 | C1, C13, C58 |  |  |  |  |  |  |  |  |  |  |  |  |  |  |  |  |  |  | 3 | Farnell | 0,000 € | 1 | 0,000 €
2 | 2 | 120p | 0805 | C14, C20 |  |  |  |  |  |  |  |  |  |  |  |  |  |  |  |  |  |  | 2 | Farnell | 0,000 € | 1 | 0,000 €
3 | 3 | 10n | 0805 | C15, C16, C18 |  |  |  |  |  |  |  |  |  |  |  |  |  |  |  |  |  |  | 3 | Farnell | 0,000 € | 1 | 0,000 €
4 | 1 | 4u7 | 1206 | C2 |  |  |  |  |  |  |  |  |  |  |  |  |  |  |  |  |  |  | 1 | Farnell | 0,000 € | 1 | 0,000 €
5 | 56 | 100n | 0603 | C3, C6, C7, C10, C11, C12, C17, C19, C21, C22, C23, C24, C25, C26, C27, C28, C29, C30, C31, C33, C34, C35, C36, C37, C38, C39, C42, C43, C44, C45, C46, C47, C48, C49, C50, C51, C52, C53, C54, C55, C57, C63, C65, C66, C67, C68, C69, C70, C72, C73, C74, C75, C76, C78, C80, C81 |  |  |  |  |  |  |  |  |  |  |  |  |  |  |  |  |  |  | 56 | Farnell | 0,000 € | 1 | 0,000 €
6 | 2 | 2u2 | 0805 | C32, C82 |  |  |  |  |  |  |  |  |  |  |  |  |  |  |  |  |  |  | 2 | Farnell | 0,000 € | 1 | 0,000 €
7 | 3 | EEEFK1V220R | 22uF 35VDC, 5x5.8mm | C4, C8, C40 | 9695834 | EEEFK1V220R | 0,241 € | 1 |  |  |  |  |  |  |  |  |  |  | EEEFK1V220R | 0,126 € | 5 |  | 3 | TME | 0,126 € | 1 | 0,126 €
8 | 3 | EEEFK1C470UR | 47uF 35VDC, 5x5.8mm | C5, C9, C41 | 9695664 | EEEFK1C470U | 0,241 € | 1 |  |  |  |  |  |  |  |  |  |  | EEEFK1C470UR | 0,173 € | 5 |  | 3 | TME | 0,173 € | 1 | 0,173 €
9 | 2 | 10u | 1210 | C56, C77 |  |  |  |  |  |  |  |  |  |  |  |  |  |  |  |  |  |  | 2 | Farnell | 0,000 € | 1 | 0,000 €
10 | 2 | 470n | 0805 | C59, C62 |  |  |  |  |  |  |  |  |  |  |  |  |  |  |  |  |  |  | 2 | Farnell | 0,000 € | 1 | 0,000 €
11 | 2 | 4n7 | 0805 | C60, C61 |  |  |  |  |  |  |  |  |  |  |  |  |  |  |  |  |  |  | 2 | Farnell | 0,000 € | 1 | 0,000 €
12 | 1 | 220n | 0805 | C64 |  |  |  |  |  |  |  |  |  |  |  |  |  |  |  |  |  |  | 1 | Farnell | 0,000 € | 1 | 0,000 €
13 | 1 | 10u | 1206 | C71 |  |  |  |  |  |  |  |  |  |  |  |  |  |  |  |  |  |  | 1 | Farnell | 0,000 € | 1 | 0,000 €
14 | 1 | EECS0HD334H | Supercap 10mm | C79 | 1751930 | EECS0HD334H | 1,820 € | 1 |  |  |  |  |  |  |  |  |  |  | EECS0HD334H | 0,950 € | 1 | 1 | 1 | TME | 0,950 € | 1 | 0,950 €
15 | 1 | NSR0240 | SOD123 | D1 |  |  |  |  |  |  |  |  |  |  |  |  |  |  |  |  |  |  | 1 | Farnell | 0,000 € | 1 | 0,000 €
16 | 3 | BAS316 | SOD323 | D2, D3, D4 |  |  |  |  |  |  |  |  |  |  |  |  |  |  |  |  |  |  | 3 | Farnell | 0,000 € | 1 | 0,000 €
17 | 1 | SM050-16 (500mA) | Fuse, 1210 | F1 |  |  |  |  |  |  |  |  |  |  |  |  |  |  | SM050-16 | 0,080 € | 10 |  | 1 | TME | 0,080 € | 1 | 0,080 €
18 | 3 | 60R@100MHz | Ferrite bead, 0603 | FB1, FB2, FB3 |  |  |  |  |  |  |  |  |  |  |  |  |  |  | LCBA-600 | 0,025 € | 25 |  | 3 | TME | 0,025 € | 1 | 0,025 €
19 | 1 | TPS61169DCKR |  | IC1 | 2542731 | TPS61169DCKR | 0,917 € | 1 |  |  |  |  |  |  |  |  |  |  |  |  |  |  | 1 | Farnell | 0,917 € | 1 | 0,917 €
20 | 1 | IS42S16400J | TSOP-II-54 | IC10 | 2253831 | IS42S16400J-7TLI | 1,950 € | 1 |  |  |  |  |  |  |  |  |  |  | IS42S16400J-7TLI | 3,150 € | 1 |  | 1 | Farnell | 1,950 € | 1 | 1,950 €
21 | 2 | SN74CBTLV3257 |  | IC11, IC14 | 1872789 | SN74CBTLV3257PWR | 0,801 € | 1 |  |  |  |  |  |  |  |  |  |  |  |  |  |  | 2 | Farnell | 0,801 € | 1 | 0,801 €
22 | 1 | SN74LVC1G02DBVR |  | IC12 | 1287579 | SN74LVC1G02DBVR | 0,284 € | 5 |  |  |  |  |  |  |  |  |  |  |  |  |  |  | 1 | Farnell | 0,284 € | 1 | 0,284 €
23 | 1 | AT25SF041-SSHDT | Serial flash, SOIC8 | IC13 | - |  |  |  |  |  |  |  |  |  |  |  |  |  | AT25SF081-SSHDT | 0,400 € | 3 |  | 1 | TME | 0,400 € | 1 | 0,400 €
24 | 1 | TPS2051BDBVR |  | IC15 | 2296067 | TPS2051BDBVR | 1,180 € | 1 |  |  |  |  |  |  |  |  |  |  |  |  |  |  | 1 | Farnell | 1,180 € | 1 | 1,180 €
25 | 1 | TPD2E001DZDR |  | IC16 | 2335446 | TPD2E001DZDR | 0,506 € | 5 |  |  |  |  |  |  |  |  |  |  |  |  |  |  | 1 | Farnell | 0,506 € | 1 | 0,506 €
26 | 1 | XE216-512-TQ128-C20 |  | IC18 | 2499221 | XE216-512-TQ128-C20 | 17,670 € | 1 |  |  |  |  |  |  |  |  |  |  |  |  |  |  | 1 | Farnell | 17,670 € | 1 | 17,670 €
27 | 2 | TPD4E001DRLR |  | IC19, IC20 | 1611469 | TPD4E001DRLR | 0,570 € | 5 |  |  |  |  |  |  |  |  |  |  |  |  |  |  | 2 | Farnell | 0,570 € | 1 | 0,570 €
28 | 3 | TPS561208DDCR |  | IC2, IC4, IC17 | 2766883 | TPS561208DDCT | 1,010 € | 1 |  |  |  |  |  |  |  |  |  |  |  |  |  |  | 3 | Farnell | 1,010 € | 1 | 1,010 €
29 | 2 | 74LVC1G07SE-7 | SC70 | IC21, IC22 | 1845213 | 74LVC1G07SE-7 | 1,530 € | 1 |  |  |  |  |  |  |  |  |  |  | 74LVC1G07SE-7 | 0,048 € | 10 |  | 2 | TME | 0,048 € | 1 | 0,048 €
30 | 1 | TPA6205A1DGN |  | IC23 | 1697151 | TPA6205A1DGN | 1,140 € | 1 |  |  |  |  |  |  |  |  |  |  |  |  |  |  | 1 | Farnell | 1,140 € | 1 | 1,140 €
31 | 1 | DP83848CVV/NOPB |  | IC24 | 1685784 | DP83848CVV/NOPB | 5,460 € | 1 |  |  |  |  |  |  |  |  |  |  |  |  |  |  | 1 | Farnell | 5,460 € | 1 | 5,460 €
32 | 1 | M95256-WMN6P | SOIC8 | IC25 | 1099712 | M95256-WMN6P | 0,321 € | 1 |  |  |  |  |  |  |  |  |  |  | M95256-WMN6P | 0,550 € | 1 |  | 1 | Farnell | 0,321 € | 1 | 0,321 €
33 | 1 | PCA21125T/Q900/1,1 | TSSOP14 | IC27 | 2400445 | PCA21125T/Q900/1,1 | 1,760 € | 1 |  |  |  |  |  |  |  |  |  |  |  |  |  |  | 1 | Farnell | 1,760 € | 1 | 1,760 €
34 | 1 | MCP23S17-E/SS |  | IC28 | 1467675 | MCP23S17-E/SS | 1,190 € | 1 |  |  |  |  |  |  |  |  |  |  | MCP23S17-E/SS | 1,130 € | 1 |  | 1 | TME | 1,130 € | 1 | 1,130 €
35 | 3 | 74VHC595MTC |  | IC3, IC5, IC26 | 2453164 | 74VHC595MT | 0,447 € | 5 |  |  |  |  |  |  |  |  |  |  |  |  |  |  | 3 | Farnell | 0,447 € | 1 | 0,447 €
36 | 1 | TPS3808G33DBVR |  | IC6 | 1703467 | TPS3808G33DBVR | 1,590 € | 1 |  |  |  |  |  |  |  |  |  |  |  |  |  |  | 1 | Farnell | 1,590 € | 1 | 1,590 €
37 | 1 | AR1021-I/SS |  | IC7 | 2218568 | AR1021-I/SS | 1,710 € | 1 |  |  |  |  |  |  |  |  |  |  | AR1021-I/SS | 2,060 € | 1 |  | 1 | Farnell | 1,710 € | 1 | 1,710 €
38 | 1 | TPS3808G09DBVR |  | IC8 | 2764653 | TPS3808G09DBV | 1,930 € | 1 |  |  |  |  |  |  |  |  |  |  |  |  |  |  | 1 | Farnell | 1,930 € | 1 | 1,930 €
39 | 1 | 74AUP1G74DC.125 |  | IC9 | 2445023 | 74AUP1G74DC.125 | 0,424 € | 5 |  |  |  |  |  |  |  |  |  |  | 74AUP1G74DC.125 | 0,323 € | 3 |  | 1 | TME | 0,323 € | 1 | 0,323 €
40 | 1 | 678038020 | USB AB mini socket | J1 |  |  |  |  |  |  |  |  |  |  |  |  |  |  | MX-67803-8020 | 0,610 € | 1 |  | 1 | TME | 0,610 € | 1 | 0,610 €
41 | 1 | 5033981892 | SD Micro; push-push | J2 |  |  |  |  |  |  |  |  |  |  |  |  |  |  | MX-503398-1892 | 1,430 € | 1 |  | 1 | TME | 1,430 € | 1 | 1,430 €
42 | 1 | DLG-0403-4R7 | Inductor 4.7uH, 0403 | L1 |  |  |  |  |  |  |  |  |  |  |  |  |  |  | DLG-0403-4R7 | 0,122 € | 10 |  | 1 | TME | 0,122 € | 1 | 0,122 €
43 | 3 | DLG-0403-2R2 | Inductor 2.2uH, 0403 | L2, L3, L4 |  |  |  |  |  |  |  |  |  |  |  |  |  |  | DLG-0403-2R2 | 0,122 € | 10 |  | 3 | TME | 0,122 € | 1 | 0,122 €
44 | 1 | PCA-6-LA-40-HL-3 | FFC horizontal, 40-pin bottom contacts | LCD1 |  |  |  |  |  |  |  |  |  |  |  |  |  |  | PCA-6-LA-40-HL-3 | 0,650 € |  |  | 1 | TME | 0,650 € | 1 | 0,650 €
45 | 5 | HSMY-C170 | LED0805 | LED1, LED2, LED3, PWR_3V3, SPEED |  |  |  |  |  |  |  |  |  |  |  |  |  |  |  |  |  |  | 5 | Farnell | 0,000 € | 1 | 0,000 €
46 | 2 | MOCD217M |  | OK1, OK2 |  |  |  |  |  |  |  |  |  |  |  |  |  |  |  |  |  |  | 2 | Farnell | 0,000 € | 1 | 0,000 €
47 | 1 | IRLML2246TRPBF |  | Q1 |  |  |  |  |  |  |  |  |  |  |  |  |  |  | IRLML2246TRPBF | 0,115 € | 5 |  | 1 | TME | 0,115 € | 1 | 0,115 €
48 | 2 | 10R | 1206 | R1, R3 |  |  |  |  |  |  |  |  |  |  |  |  |  |  |  |  |  |  | 2 | Farnell | 0,000 € | 1 | 0,000 €
49 | 7 | 47K | 0805 | R10, R12, R19, R20, R21, R26, R37 |  |  |  |  |  |  |  |  |  |  |  |  |  |  |  |  |  |  | 7 | Farnell | 0,000 € | 1 | 0,000 €
50 | 3 | 20K | 0805 | R11, R32, R38 |  |  |  |  |  |  |  |  |  |  |  |  |  |  |  |  |  |  | 3 | Farnell | 0,000 € | 1 | 0,000 €
51 | 1 | 3K3 | 0805 | R17 |  |  |  |  |  |  |  |  |  |  |  |  |  |  |  |  |  |  | 1 | Farnell | 0,000 € | 1 | 0,000 €
52 | 1 | 4K7 | 0805 | R18 |  |  |  |  |  |  |  |  |  |  |  |  |  |  |  |  |  |  | 1 | Farnell | 0,000 € | 1 | 0,000 €
53 | 3 | 0R | 0805 | R2, R67, JP1 |  |  |  |  |  |  |  |  |  |  |  |  |  |  |  |  |  |  | 3 | Farnell | 0,000 € | 1 | 0,000 €
54 | 1 | 43R2 | 0805 | R22 |  |  |  |  |  |  |  |  |  |  |  |  |  |  |  |  |  |  | 1 | Farnell | 0,000 € | 1 | 0,000 €
55 | 1 | 56K | 0805 | R23 |  |  |  |  |  |  |  |  |  |  |  |  |  |  |  |  |  |  | 1 | Farnell | 0,000 € | 1 | 0,000 €
56 | 6 | 33R | 0603 | R25, R27, R28, R29, R30, R39 |  |  |  |  |  |  |  |  |  |  |  |  |  |  |  |  |  |  | 6 | Farnell | 0,000 € | 1 | 0,000 €
57 | 2 | 4R7 | 0805 | R6, R31 |  |  |  |  |  |  |  |  |  |  |  |  |  |  |  |  |  |  | 2 | Farnell | 0,000 € | 1 | 0,000 €
58 | 4 | 1K | 0805 | R33, R34, R65, R66 |  |  |  |  |  |  |  |  |  |  |  |  |  |  |  |  |  |  | 4 | Farnell | 0,000 € | 1 | 0,000 €
59 | 1 | 15K | 0805 | R4 |  |  |  |  |  |  |  |  |  |  |  |  |  |  |  |  |  |  | 1 | Farnell | 0,000 € | 1 | 0,000 €
60 | 4 | 49R9 | 0805 | R40, R41, R44, R47 |  |  |  |  |  |  |  |  |  |  |  |  |  |  |  |  |  |  | 4 | Farnell | 0,000 € | 1 | 0,000 €
61 | 1 | 22R | 0805 | R42 |  |  |  |  |  |  |  |  |  |  |  |  |  |  |  |  |  |  | 1 | Farnell | 0,000 € | 1 | 0,000 €
62 | 5 | 2K2 | 0805 | R43, R46, R48, R51, R52 |  |  |  |  |  |  |  |  |  |  |  |  |  |  |  |  |  |  | 5 | Farnell | 0,000 € | 1 | 0,000 €
63 | 5 | 180R | 0805 | R5, R45, R49, R50, R54 |  |  |  |  |  |  |  |  |  |  |  |  |  |  |  |  |  |  | 5 | Farnell | 0,000 € | 1 | 0,000 €
64 | 1 | 4K87 | 0603 | R53 |  |  |  |  |  |  |  |  |  |  |  |  |  |  |  |  |  |  | 1 | Farnell | 0,000 € | 1 | 0,000 €
65 | 8 | 470R | 0805 | R55, R56, R57, R58, R59, R60, R63, R64 |  |  |  |  |  |  |  |  |  |  |  |  |  |  |  |  |  |  | 8 | Farnell | 0,000 € | 1 | 0,000 €
66 | 9 | 10K | 0805 | R7, R9, R13, R14, R15, R16, R24, R35, R36 |  |  |  |  |  |  |  |  |  |  |  |  |  |  |  |  |  |  | 9 | Farnell | 0,000 € | 1 | 0,000 €
67 | 2 | 220R | 0805 | R61, R62 |  |  |  |  |  |  |  |  |  |  |  |  |  |  |  |  |  |  | 2 | Farnell | 0,000 € | 1 | 0,000 €
68 | 1 | 2K7 | 0805 | R8 |  |  |  |  |  |  |  |  |  |  |  |  |  |  |  |  |  |  | 1 | Farnell | 0,000 € | 1 | 0,000 €
69 | 1 | LD-BZEN-0803 | Buzzer | SP1 |  |  |  |  |  |  |  |  |  |  |  |  |  |  | LD-BZEN-0803 | 0,696 € | 10 |  | 1 | TME | 0,696 € | 1 | 0,696 €
70 | 1 | 1301.9316 | Reset switch | SW1 |  |  |  |  |  |  |  |  |  |  |  |  |  |  | 1301.9316 | 0,230 € | 10 | 1 | 1 | TME | 0,230 € | 1 | 0,230 €
71 | 1 | FC68149 | DC input plug, 5,5/2,5mm | X1 |  |  |  |  |  |  |  |  |  |  |  |  |  |  | FC68149 | 0,521 € | 1 | 1 |  | TME | 0,521 € | 1 | 0,521 €
72 | 1 | SSW-105-02-S-D |  | X2 |  |  |  |  |  |  |  |  |  |  |  |  |  |  |  |  |  | 1 |  | Farnell | 0,000 € | 1 | 0,000 €
73 | 1 | TSW-104-02-S-D_NN |  | X3 |  |  |  |  |  |  |  |  |  |  |  |  |  |  |  |  |  | 1 |  | Farnell | 0,000 € | 1 | 0,000 €
74 | 1 | TSW-103-07-F-D |  | X4 |  |  |  |  |  |  |  |  |  |  |  |  |  |  |  |  |  | 1 |  | Farnell | 0,000 € | 1 | 0,000 €
75 | 1 | ZL231-20KG | 20-pin IDC right angle | X5 |  |  |  |  |  |  |  |  |  |  |  |  |  |  | ZL231-20KG | 0,271 € | 2 | 1 |  | TME | 0,271 € | 1 | 0,271 €
76 | 1 | 22-23-2021 |  | X6 |  |  |  |  |  |  |  |  |  |  |  |  |  |  |  |  |  | 1 |  | Farnell | 0,000 € | 1 | 0,000 €
77 | 1 | LMJTAB881243M-L | RJ45 Ethernet jack | X7 |  |  |  |  |  |  |  |  |  |  |  |  |  |  | LMJTAB881243M-L | 3,170 € | 1 | 1 |  | TME | 3,170 € | 1 | 3,170 €
78 | 1 | SSW-107-02-S-D |  | X8 |  |  |  |  |  |  |  |  |  |  |  |  |  |  |  |  |  | 1 |  | Farnell | 0,000 € | 1 | 0,000 €
79 | 1 | CFPS-73-24M | Xtal oscillator | XO1 |  |  |  |  |  |  |  |  |  |  |  |  |  |  | CFPS-73-24M | 2,460 € | 1 |  | 1 | TME | 2,460 € | 1 | 2,460 €
80 | 1 | CFPS-73-25M | Xtal oscillator | XO2 |  |  |  |  |  |  |  |  |  |  |  |  |  |  | CFPS-73-25M | 2,460 € | 1 |  | 1 | TME | 2,460 € | 1 | 2,460 €
81 | 1 | XTAL016178- 85SMX | RTC xtal | Y1 |  |  |  |  |  |  |  |  |  |  |  |  |  |  |  |  |  |  | 1 | Farnell | 0,000 € | 1 | 0,000 €
82 | 3 | P4SMAJ16A-DIO |  | ZD3, ZD7, ZD8 |  |  |  |  |  |  |  |  |  |  |  |  |  |  |  |  |  |  | 3 | Farnell | 0,000 € | 1 | 0,000 €
83 | 3 | P4SMAJ5.0A-DIO |  | ZD4, ZD5, ZD6 |  |  |  |  |  |  |  |  |  |  |  |  |  |  |  |  |  |  | 3 | Farnell | 0,000 € | 1 | 0,000 €
84 | 1 | Option #1: RFE43BH-AIW-DNS | 4.3” 480x272 LCD with resistive touch screen |  |  |  |  |  |  |  |  |  |  |  |  |  |  |  | RFE43BH-AIW-DNS | 24,810 € | 1 | - | - | TME | 24,810 € | 1 | 24,810 €
 |  | Option #2: RFE430Y-AIW-DNS | 4.3” 480x272 LCD with resistive touch screen |  |  |  |  |  |  |  |  |  |  |  |  |  |  |  | RFE430Y-AIW-DNS
 |  |  |  |  |  |  |  |  |  |  |  |  |  |  |  |  |  |  | Total components |  |  | 10 | 212 |  |  | Total | 80,168 €
 | Optional / not installed
 | 1 | ZL262-10DG | ETH_W5500_MODULE | MOD1
 | 1 | PCA-6G-20-HL-3 or 52746-207 | FFC horizontal, 20-pin bottom contacts | X9
 | 1 | ??? | SOD323 | ZD2

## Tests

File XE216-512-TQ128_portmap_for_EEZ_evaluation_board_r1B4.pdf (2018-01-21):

xCORE-200_PortMap

SDRAM
Key: | Port unavailable if USB enabled on that tile | LCD
Port unavailable if RGMII enabled | Ethernet
Port unavailable if RGMII or USB enabled on tile 1 / tile 3 (as appropriate) | USB
Note: I/O rail supply column only applies in packages where VDDIO is spplit into L and R. Please refer to the product datasheet. | System
Port | Reserved Pins | Features | Pin name | I/O direction
1b | 4b | 8b | 16b | 32b | Link | QSPI | RGMII | I/O rail | BANK Drive mA | TQ128

Tile

0

P1A0 | IOL | 0 | 4 | X0D00 | 30 | Out | SD_RAS
P1B0 | | | | | xlink3_tx2 | SS | IOL | 0 | 4 | X0D01 | 27 | Out | SD_CAS
| P4A0 | P8A0 | P16A0 | P32A20 | | | IOL | 0 | 4 | X0D02 | 37 | In/out | SD_ADQ0
| P4A1 | P8A1 | P16A1 | P32A21 | | | IOL | 0 | 4 | X0D03 | 38 | In/out | SD_ADQ1
| P4B0 | P8A2 | P16A2 | P32A22 | | IO0 | IOL | 0 | 4 | X0D04 | 31 | In/out | SD_ADQ2
| P4B1 | P8A3 | P16A3 | P32A23 | | IO1 | IOL | 0 | 4 | X0D05 | 33 | In/out | SD_ADQ3
| P4B2 | P8A4 | P16A4 | P32A24 | | IO2 | IOL | 0 | 4 | X0D06 | 34 | In/out | SD_ADQ4
| P4B3 | P8A5 | P16A5 | P32A25 | | IO3 | IOL | 0 | 4 | X0D07 | 35 | In/out | SD_ADQ5
| P4A2 | P8A6 | P16A6 | P32A26 | | | IOL | 0 | 4 | X0D08 | 39 | In/out | SD_ADQ6
| P4A3 | P8A7 | P16A7 | P32A27 | | | IOL | 0 | 4 | X0D09 | 40 | In/out | SD_ADQ7
P1C0 | | | | | xlink3_tx3 | QSCLK | IOL | 0 | 4 | X0D10 | 28 | Out | SD_WE
P1D0 | | | | | | | IOL | 0 | 4 | X0D11 | 32 | Out (PWM) | LCD_BRIGHTNESS
P1E0 | | | | | | | IOR | 1 | 4 | X0D12 | 62 | Out (PWM) | AUDIO_OUT
P1F0 | | | | | | | IOR | 1 | 4 | X0D13 | 63 | Out | SD_CLK
| P4C0 | P8B0 | P16A8 | P32A28 | | | IOR | 1 | 4 | X0D14 | 57 | In/out | SD_ADQ8
| P4C1 | P8B1 | P16A9 | P32A29 | | | IOR | 1 | 4 | X0D15 | 58 | In/out | SD_ADQ9
| P4D0 | P8B2 | P16A10 | | xlink4_rx4 | | IOR | 1 | 4 | X0D16 | 68 | In/out | SD_ADQ10
| P4D1 | P8B3 | P16A11 | | xlink4_rx3 | | IOR | 1 | 4 | X0D17 | 69 | In/out | SD_ADQ11
| P4D2 | P8B4 | P16A12 | | xlink4_rx2 | | IOR | 1 | 4 | X0D18 | 70 | In/out | SD_ADQ12
| P4D3 | P8B5 | P16A13 | | xlink4_rx1 | | IOR | 1 | 4 | X0D19 | 71 | In/out | SD_ADQ13/BA0
| P4C2 | P8B6 | P16A14 | P32A30 | | | IOR | 1 | 4 | X0D20 | 59 | In/out | SD_ADQ14/BA1
| P4C3 | P8B7 | P16A15 | P32A31 | | | IOR | 1 | 4 | X0D21 | 61 | In/out | SD_ADQ15
P1G0 | | | | | | | IOR | 1 | 4 | X0D22 | 64 | Out | LCD_VSYNC
P1H0 | | | | | | | IOR | 1 | 4 | X0D23 | 66 | Out | LCD_DE
P1I0 | | | | | xlink7_rx0 | | IOR | 2 | 4 | X0D24 | 88 | Out | LCD_CLK
P1J0 | | | | | xlink7_tx0 | | IOR | 2 | 4 | X0D25 | 89 | Out | LCD_HSYNC
| P4E0 | P8C0 | P16B0 | | xlink7_tx3 | | IOR | 2 | 4 | X0D26 | 93 | Out | SPI0_MOSI
| P4E1 | P8C1 | P16B1 | | xlink7_tx4 | | IOR | 2 | 4 | X0D27 | 94 | Out | SPI1_CLK
| P4F0 | P8C2 | P16B2 | | | | IOR | 2 | 4 | X0D28 | 96 | Out | SPI2_CLK
| P4F1 | P8C3 | P16B3 | | | | IOR | 2 | 4 | X0D29 | 98 | Out | SPI2_MOSI
| P4F2 | P8C4 | P16B4 | | | | IOR | 2 | 4 | X0D30 | 99 | Out | SPI1_MOSI
| P4F3 | P8C5 | P16B5 | | | | IOR | 2 | 4 | X0D31 | 100 | Out | SPI0_CLK

XE2xx
package pin

EEZ eval. board
function

Key: | Port unavailable if USB enabled on that tile | LCD
Port unavailable if RGMII enabled | Ethernet
Port unavailable if RGMII or USB enabled on tile 1 / tile 3 (as appropriate) | USB
Note: I/O rail supply column only applies in packages where VDDIO is spplit into L and R. Please refer to the product datasheet. | System
Port | Reserved Pins | Features | Pin name | I/O direction
1b | 4b | 8b | 16b | 32b | Link | QSPI | RGMII | I/O rail | BANK Drive mA | TQ128 XE2xx package pin

EEZ eval. board
function
| P4E2 | P8C6 | P16B6 | | IOR | 2 | 4 | X0D32 | 95 | Out | SPI0_STROBE
| P4E3 | P8C7 | P16B7 | | IOR | 2 | 4 | X0D33 | 97 | Out | SPI1_SELECT
P1K0 | | | | xlink7_tx1 | IOR | 2 | 4 | X0D34 | 90 | Out | SPI2_SELECT
P1L0 | | | | xlink7_tx2 | IOR | 2 | 4 | X0D35 | 91 | In | SPI1_MISO
P1M0 | | P8D0 | P16B8 | | IOL | 3 | 4 | X0D36 | 3 | In | SPI2_MISO
P1N0 | | P8D1 | P16B9 | xlink0_rx4 | IOL | 3 | 4 | X0D37 | 4 | In | SPI0_TOUCH
P1O0 | | P8D2 | P16B10 | xlink0_rx3 | IOL | 3 | 4 | X0D38 | 5 | In/out | GPIO38
P1P0 | | P8D3 | P16B11 | xlink0_rx2 | IOL | 3 | 4 | X0D39 | 7 | In/out | GPIO39
| | P8D4 | P16B12 | xlink0_rx1 | IOL | 3 | 4 | X0D40 | 8 | In/out | XL_DN1 (Debug)
| | P8D5 | P16B13 | xlink0_rx0 | IOL | 3 | 4 | X0D41 | 9 | In/out | XL_DN0 (Debug)
| | P8D6 | P16B14 | xlink0_tx0 | IOL | 3 | 4 | X0D42 | 10 | In/out | XL_UP0 (Debug)
| | P8D7 | P16B15 | xlink0_tx1 | IOL | 3 | 4 | X0D43 | 12 | In/out | XL_UP1 (Debug)

Key: | Port unavailable if USB enabled on that tile | LCD
Port unavailable if RGMII enabled | Ethernet
Port unavailable if RGMII or USB enabled on tile 1 / tile 3 (as appropriate) | USB
Note: I/O rail supply column only applies in packages where VDDIO is spplit into L and R. Please refer to the product datasheet. | System
Port | Reserved Pins | Features | Pin name | I/O direction
1b | 4b | 8b | 16b | 32b | Link | QSPI | RGMII | I/O rail | BANK Drive mA | TQ128 XE2xx package pin

EEZ eval. board
function

## Tile 1

P1A0 | | | | | xlink7_rx2 | | IOR | 0 | 4 | X1D00 | 85 | n/a | Eth lib reserved
P1B0 | | | | | xlink7_rx1 | | IOR | 0 | 4 | X1D01 | 86 | n/a | Eth lib reserved
| P4A0 | P8A0 | P16A0 | P32A20 | xlink4_rx0 | | IOR | 0 | 4 | X1D02 | 72 | n/a | USB lib?
| P4A1 | P8A1 | P16A1 | P32A21 | xlink4_tx0 | | IOR | 0 | 4 | X1D03 | 74 | n/a | USB lib?
| P4B0 | P8A2 | P16A2 | P32A22 | xlink4_tx1 | | IOR | 0 | 4 | X1D04 | 75 | n/a | USB lib?
| P4B1 | P8A3 | P16A3 | P32A23 | xlink4_tx2 | | IOR | 0 | 4 | X1D05 | 76 | n/a | USB lib?
| P4B2 | P8A4 | P16A4 | P32A24 | xlink4_tx3 | | IOR | 0 | 4 | X1D06 | 77 | n/a | USB lib?
| P4B3 | P8A5 | P16A5 | P32A25 | xlink4_tx4 | | IOR | 0 | 4 | X1D07 | 79 | n/a | USB lib?
| P4A2 | P8A6 | P16A6 | P32A26 | xlink7_rx4 | | IOR | 0 | 4 | X1D08 | 82 | n/a | USB lib?
| P4A3 | P8A7 | P16A7 | P32A27 | xlink7_rx3 | | IOR | 0 | 4 | X1D09 | 84 | n/a | USB lib?
P1C0 | | | | | | | IOT | 0 | 4 | X1D10 | 121 | In/out | MDIO
P1D0 | | | | | | | IOT | 0 | 4 | X1D11 | 122 | Out | MDC
P1E0 | | | | | | | IOL | 1 | 4 | X1D12 | N.C.
P1F0 | | | | | | | IOL | 1 | 4 | X1D13 | N.C.
| P4C0 | P8B0 | P16A8 | P32A28 | | | IOR | 1 | 4 | X1D14 | 51 | n/a | Eth lib dummy
| P4C1 | P8B1 | P16A9 | P32A29 | | | IOR | 1 | 4 | X1D15 | 53 | n/a | Eth lib dummy
| P4D0 | P8B2 | P16A10 | | xlink3_rx1 | | IOL | 1 | 4 | X1D16 | 22 | n/a | Eth lib dummy
| P4D1 | P8B3 | P16A11 | | xlink3_rx0 | | IOL | 1 | 4 | X1D17 | 23 | n/a | Eth lib dummy
| P4D2 | P8B4 | P16A12 | | xlink3_tx0 | | IOL | 1 | 4 | X1D18 | 25 | n/a | Eth lib dummy
| P4D3 | P8B5 | P16A13 | | xlink3_tx1 | | IOL | 1 | 4 | X1D19 | 26 | n/a | Eth lib dummy
| P4C2 | P8B6 | P16A14 | P32A30 | | | IOR | 1 | 4 | X1D20 | 54 | n/a | Eth lib dummy
| P4C3 | P8B7 | P16A15 | P32A31 | | | IOR | 1 | 4 | X1D21 | 55 | n/a | Eth lib dummy
P1G0 | | | | | xlink3_tx4 | | IOL | 1 | 4 | X1D22 | N.C.
P1H0 | | | | | | | IOL | 1 | 4 | X1D23 | N.C.
P1I0 | | | | | | | IOR | 2 | 4 | X1D24 | N.C.
P1J0 | | | | | | | IOR | 2 | 4 | X1D25 | N.C.
| P4E0 | P8C0 | P16B0 | | | tx_clk | IOT | 2 | 8 | X1D26 | 112 | Out | TX_CLK
| P4E1 | P8C1 | P16B1 | | | tx_ctl | IOT | 2 | 8 | X1D27 | 113 | Out | TX_CTL
| P4F0 | P8C2 | P16B2 | | | rx_clk | IOT | 2 | 4 | X1D28 | 114 | In | RX_CLK
| P4F1 | P8C3 | P16B3 | | | rx_ctl | IOT | 2 | 4 | X1D29 | 115 | In | RX_CTL
| P4F2 | P8C4 | P16B4 | | | rx0 | IOT | 2 | 4 | X1D30 | 116 | In | RX0
| P4F3 | P8C5 | P16B5 | | | rx1 | IOT | 2 | 4 | X1D31 | 117 | In | RX1

Key: | Port unavailable if USB enabled on that tile | LCD
Port unavailable if RGMII enabled | Ethernet
Port unavailable if RGMII or USB enabled on tile 1 / tile 3 (as appropriate) | USB
Note: I/O rail supply column only applies in packages where VDDIO is spplit into L and R. Please refer to the product datasheet. | System
Port | Reserved Pins | Features | Pin name | I/O direction
1b | 4b | 8b | 16b | 32b | Link | QSPI | RGMII | I/O rail | BANK Drive mA | TQ128 XE2xx package pin

EEZ eval. board
function
| P4E2 | P8C6 | P16B6 | | rx2 | IOT | 2 | 4 | X1D32 | 118 | In | RX2
| P4E3 | P8C7 | P16B7 | | rx3 | IOT | 2 | 4 | X1D33 | 119 | In | RX3
P1K0 | | | | xlink0_tx2 | | IOL | 2 | 4 | X1D34 | N.C.
P1L0 | | | | xlink0_tx3 | | IOL | 2 | 4 | X1D35 | 13 | In | SPI_INT
P1M0 | | P8D0 | P16B8 | xlink0_tx4 | | IOL | 3 | 4 | X1D36 | 15 | In | ETH_RX_ER
P1N0 | | P8D1 | P16B9 | xlink3_rx4 | | IOL | 3 | 4 | X1D37 | 18 | Out | ETH_RST
P1O0 | | P8D2 | P16B10 | xlink3_rx3 | | IOL | 3 | 4 | X1D38 | 20
P1P0 | | P8D3 | P16B11 | xlink3_rx2 | | IOL | 3 | 4 | X1D39 | 21
| | P8D4 | P16B12 | | tx3 | IOT | 3 | 8 | X1D40 | 106 | In/out | TX3
| | P8D5 | P16B13 | | tx2 | IOT | 3 | 8 | X1D41 | 107 | Out | TX2
| | P8D6 | P16B14 | | tx1 | IOT | 3 | 8 | X1D42 | 108 | Out | TX1
| | P8D7 | P16B15 | | tx0 | IOT | 3 | 8 | X1D43 | 109 | Out | TX0

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

EEZ eval. board
function

U

S

B 0

USB_DM | 47 | USB_D_N
USB_DP | 46 | USB_D_P
USB_ID | 43 | TP6 (test point)
USB_RTUNE | 48 | Resistor 43R2 to GND
USB_VBUS | 45 | USB_VBUS
USB_VDD | 49 | 1V0
CLK | 125 | 24M_CLK
RST_N | 124 | RST_N
TCK | 128 | TCK (Debug)
TDI | 2 | TDI (Debug)
TDO | 1 | TDO (Debug)
TMS | 127 | TMS (Debug)
TRST_N | 123 | RST_N
PLL_AVDD | 103 | 1V0
PLL_AGND | 104 | GND
OTP_VCC | 105 | 3V3
VSS | PADDLE | GND
VDD | 101 102 11 120 126 16 17 24 36 41 56 60 73 80 81 87 | 1V0
USB_VDD33 | 44 | 3V3
VDDIOL | 6 14 19 29 42 | 3V3
VDDIOR | 52 67 78 83 92 | 3V3
VDDIOT | 110 111 | 3V3

Power/Gnd/JT

A

G

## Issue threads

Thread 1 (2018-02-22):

GND is not connected properly on X1 DC jack

prasimix, 2018-02-22:
Connect both pin 1 and 3 to the GND.

prasimix, 2018-02-24:
Fixed

Closed 2018-02-24.

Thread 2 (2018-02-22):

QSPI mux control is inverted

prasimix, 2018-02-22:
QSPI mux signal used to control IC11 and IC14 is inverted. Has to be connected to pin 5 of IC9 instead of pin 3.

prasimix, 2018-02-24:
Fixed

Closed 2018-02-24.

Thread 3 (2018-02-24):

Add jumper to LCD Reset input

prasimix, 2018-02-24:
Add jumper to LCD pin 36 to select Reset or GND that LCDs such as RFE43BH-AIW-DNS can be used.

prasimix, 2018-02-24:
Fixed

Closed 2018-02-24.

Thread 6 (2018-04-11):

Touchscreen controller wiring

prasimix, 2018-04-11:
* Move M1 from Vss to Vdd (for SPI communication)
* Move WAVE from Y- to X-
* Connect M2 to Vss for 4-wire sensor

prasimix, 2018-04-11:
Fixed

Closed 2018-04-11.

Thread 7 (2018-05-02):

Wrong connection of DP83848C "reserved" pins

prasimix, 2018-05-02:
DP83848C pin 20 and 21 are wrongly connected to GND instead of +3V3

prasimix, 2018-05-02:
Fixed

Closed 2018-05-02.

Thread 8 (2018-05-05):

Micro SD card pinout mismatch

prasimix, 2018-05-05:
Micro SD card socket (J2) pins are wrongly connected (shifted up for one pin!).

prasimix, 2018-05-05:
Fixed

Closed 2018-05-05.

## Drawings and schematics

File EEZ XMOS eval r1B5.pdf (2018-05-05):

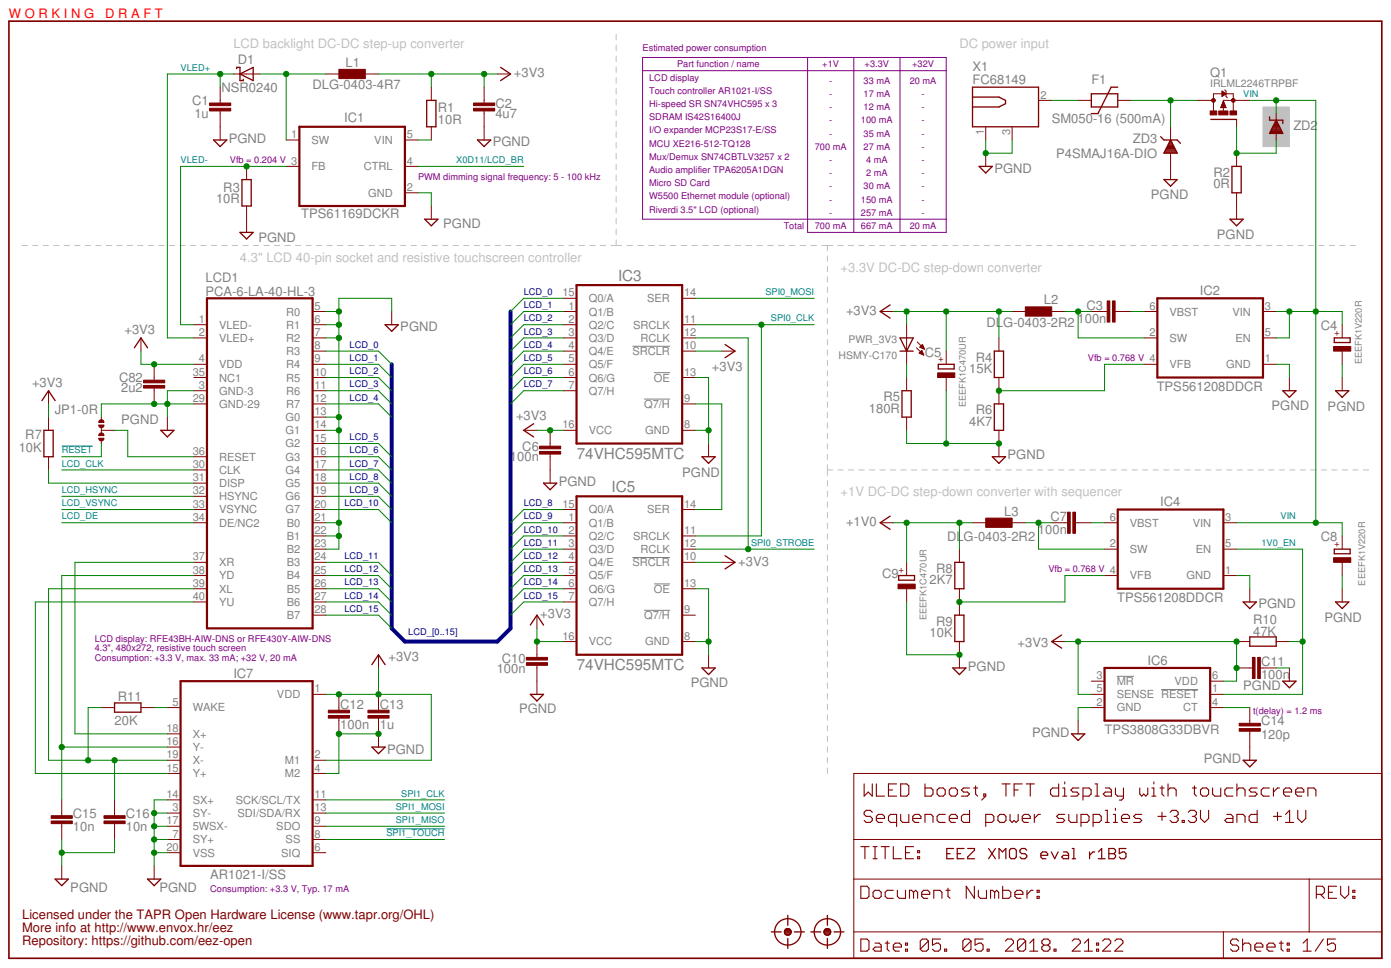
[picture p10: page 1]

Part function / name | +1V | +3.3V | +32V

LCD display Touch controller AR1021-I/SS Hi-speed SR SN74VHC595 x 3 SDRAM IS42S16400J I/O expander MCP23S17-E/SS W5500 Ethernet module (optional) MCU XE216-512-TQ128 Mux/Demux SN74CBTLV3257 x 2 Micro SD Card Total Riverdi 3.5" LCD (optional) | -----700 mA --700 mA --- | 33 mA 17 mA 12 mA 100 mA 35 mA 27 mA 4 mA 2 mA 667 mA 30 mA 150 mA 257 mA | 20 mA ------ Audio amplifier TPA6205A1DGN -20 mA - PWM dimming signal frequency: 5 - 100 kHz --

+3.3V DC-DC step-down converter

+1V DC-DC step-down converter with sequencer

LCD display: RFE43BH-AIW-DNS or RFE430Y-AIW-DNS
4.3", 480x272, resistive touch screen
Consumption: +3.3 V, max. 33 mA; +32 V, 20 mA

Licensed under the TAPR Open Hardware License (www.tapr.org/OHL)
Repository: https://github.com/eez-open More info at http://www.envox.hr/eez

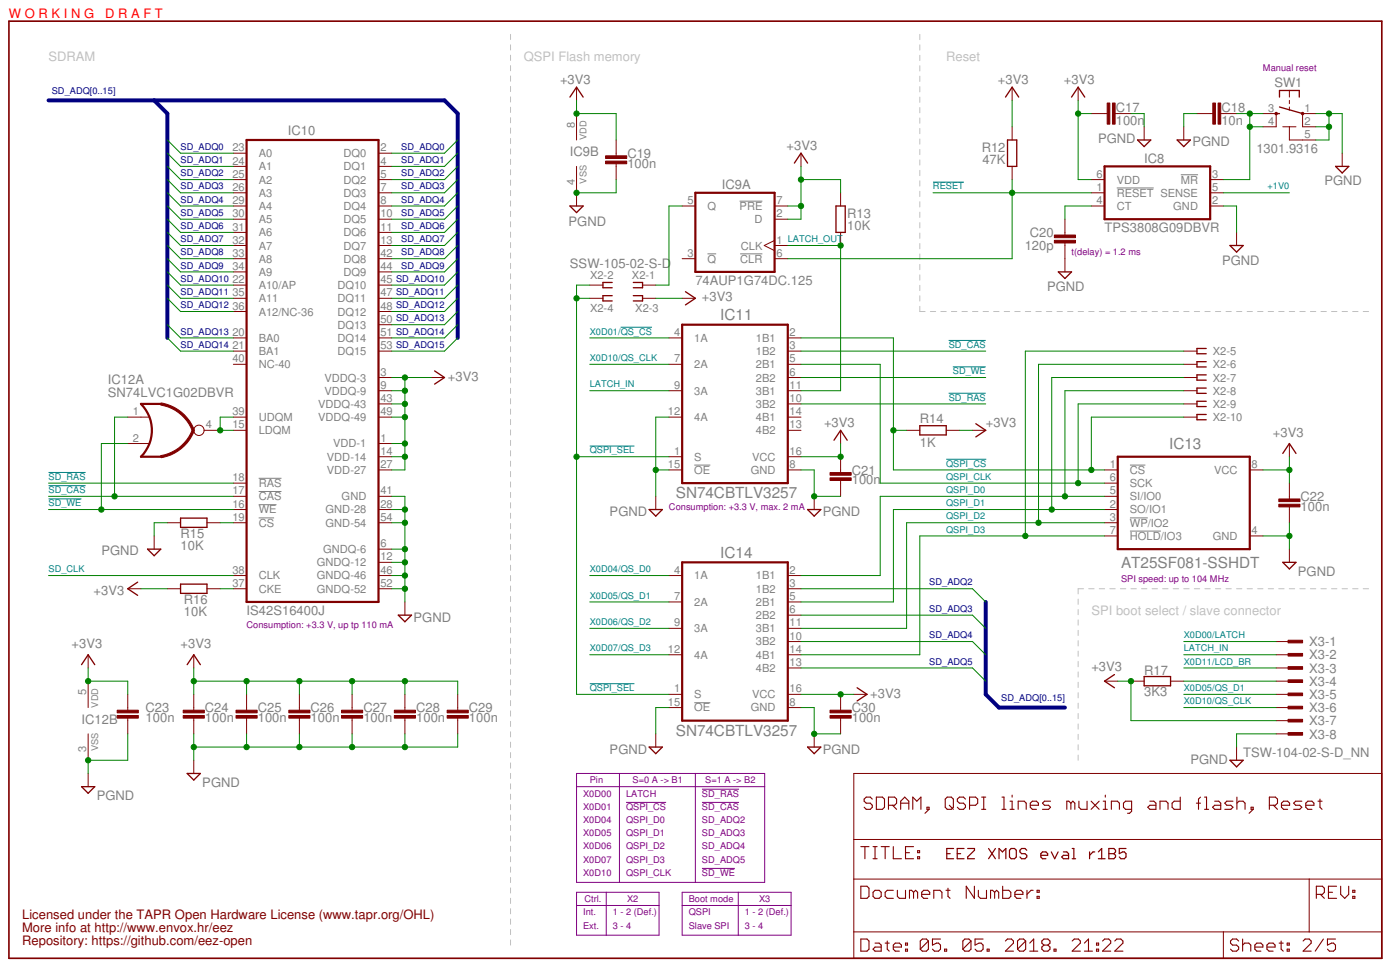
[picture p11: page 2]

SPI boot select / slave connector AT25SF081-SSHDT
SPI speed: up to 104 MHz

Consumption: +3.3 V, up tp 110 mA

S=0 A -> B1 LATCH QSPI_CS QSPI_D0 QSPI_D1 QSPI_D2 QSPI_D3 QSPI_CLK | S=1 A -> B2 X0D00 X0D01 X0D04 X0D05 X0D06 X0D07 X0D10 SD_RAS SD_CAS SD_ADQ2 SD_ADQ3 SD_ADQ4 SD_ADQ5 SD_WE

Pin

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

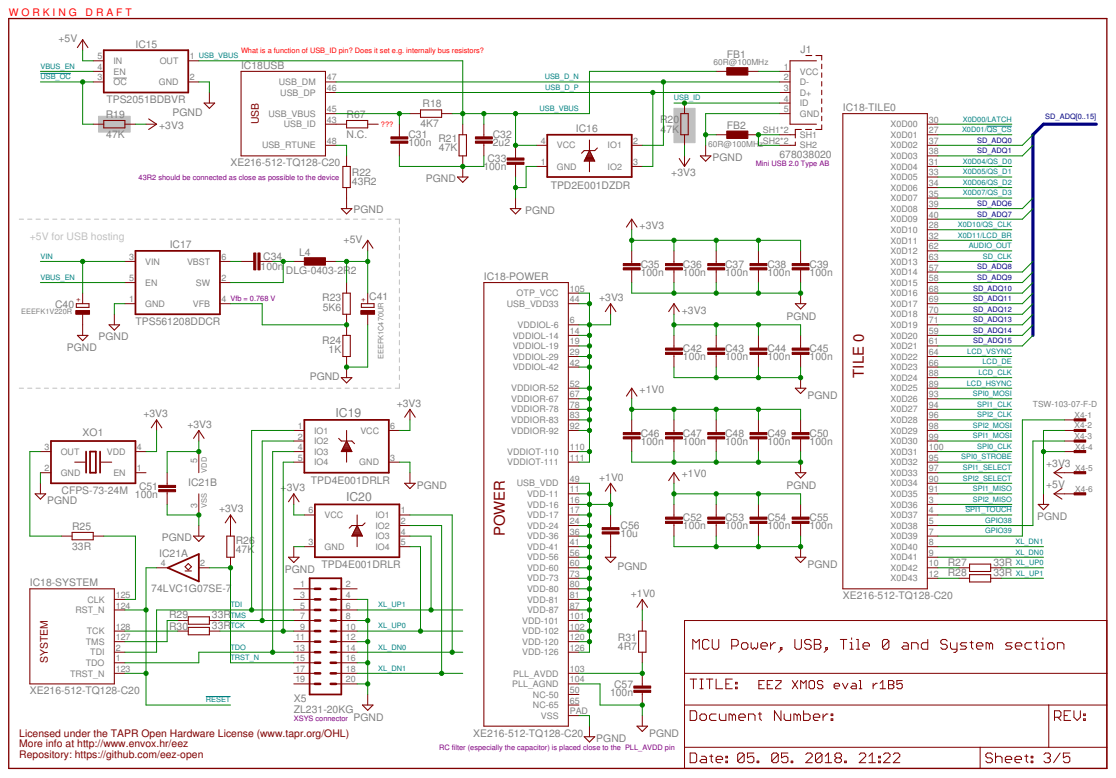
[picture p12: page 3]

Mini USB 2.0 Type AB

43R2 should be connected as close as possible to the device

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

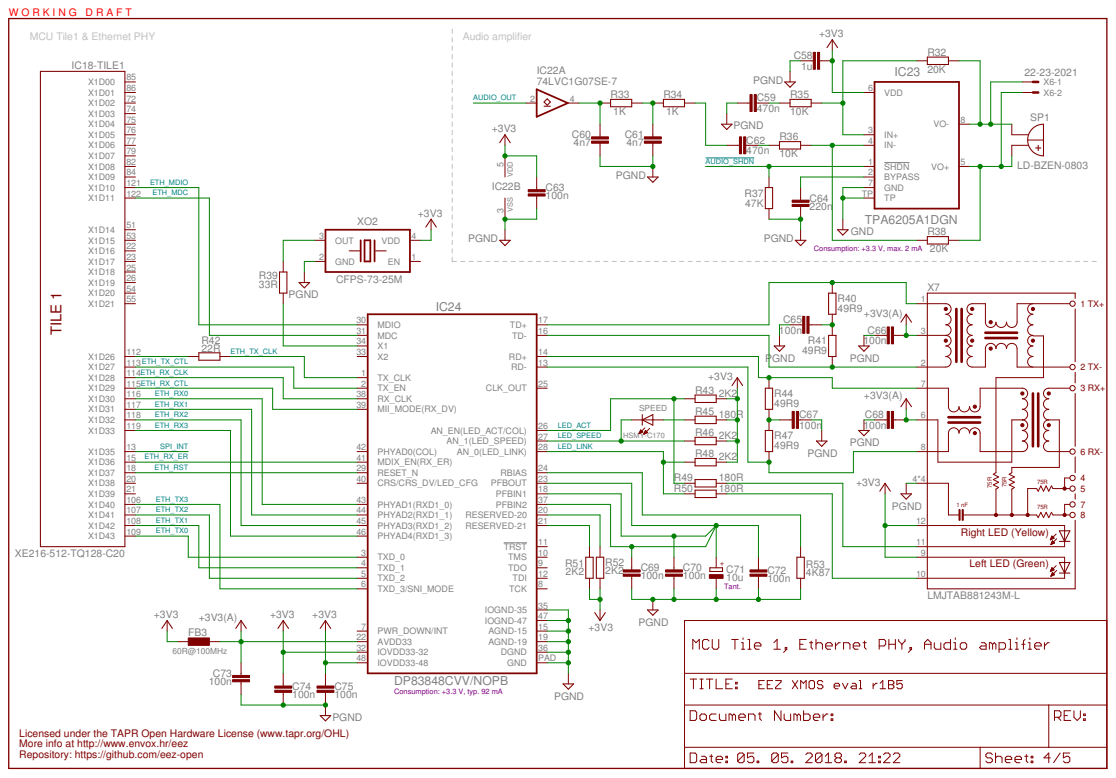
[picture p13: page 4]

ETH_TX0 ETH_TX1 ETH_TX2 ETH_TX3 ETH_RST SPI_INT ETH_RX_ER | 40

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

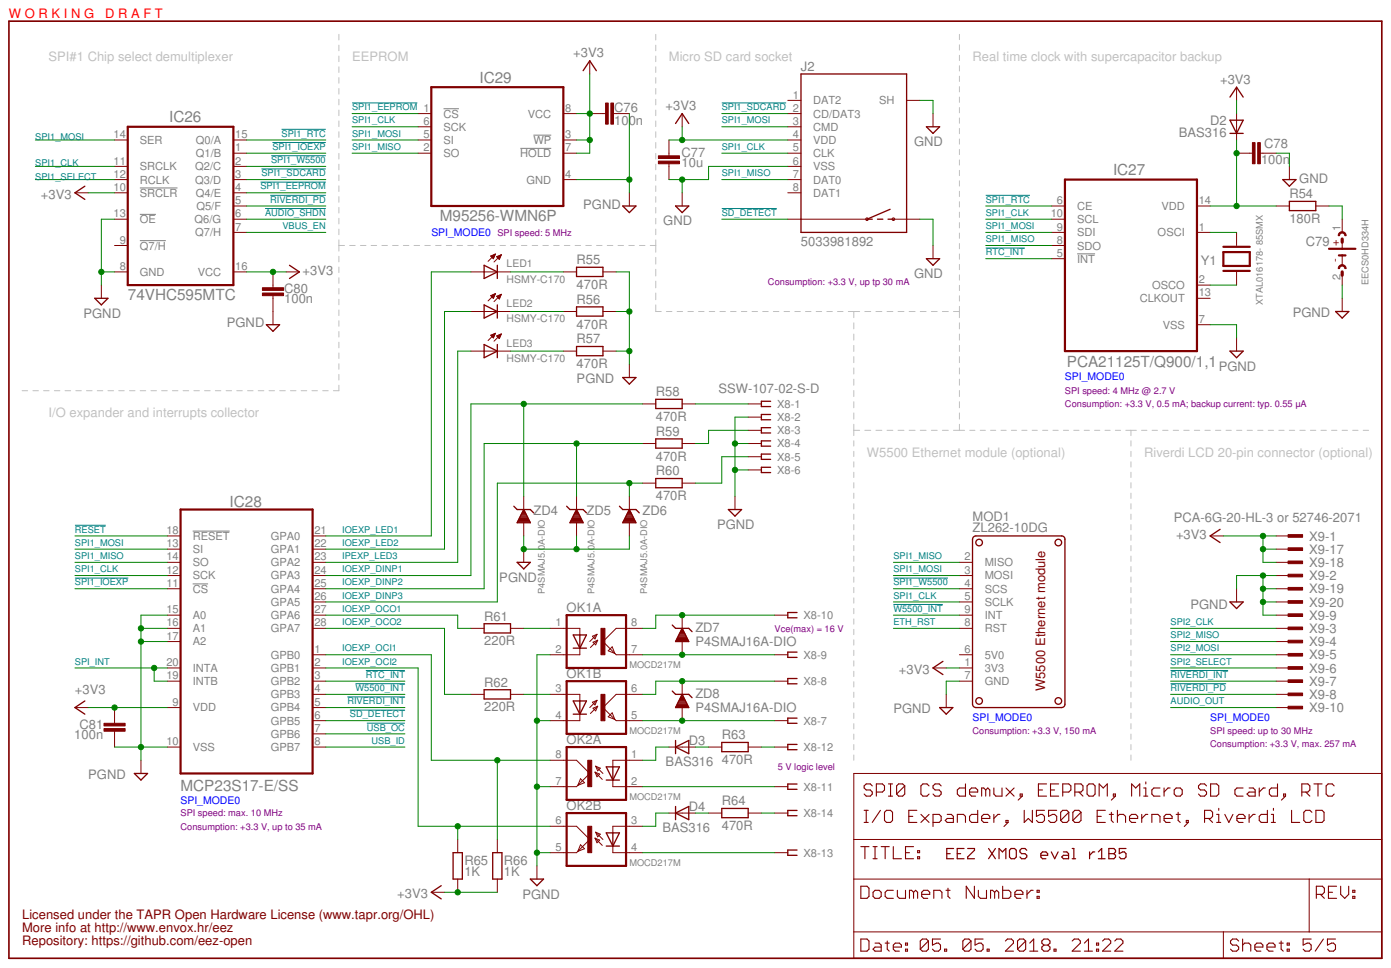
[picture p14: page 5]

SPI#1 Chip select demultiplexer

Real time clock with supercapacitor backup

Consumption: +3.3 V, up tp 30 mA

PCA21125T/Q900/1,1
SPI_MODE0
SPI speed: 4 MHz @ 2.7 V
Consumption: +3.3 V, 0.5 mA; backup current: typ. 0.55 μA

I/O expander and interrupts collector

Riverdi LCD 20-pin connector (optional)

VSS
MCP23S17-E/SS
SPI speed: max. 10 MHz Consumption: +3.3 V, up to 35 mA

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

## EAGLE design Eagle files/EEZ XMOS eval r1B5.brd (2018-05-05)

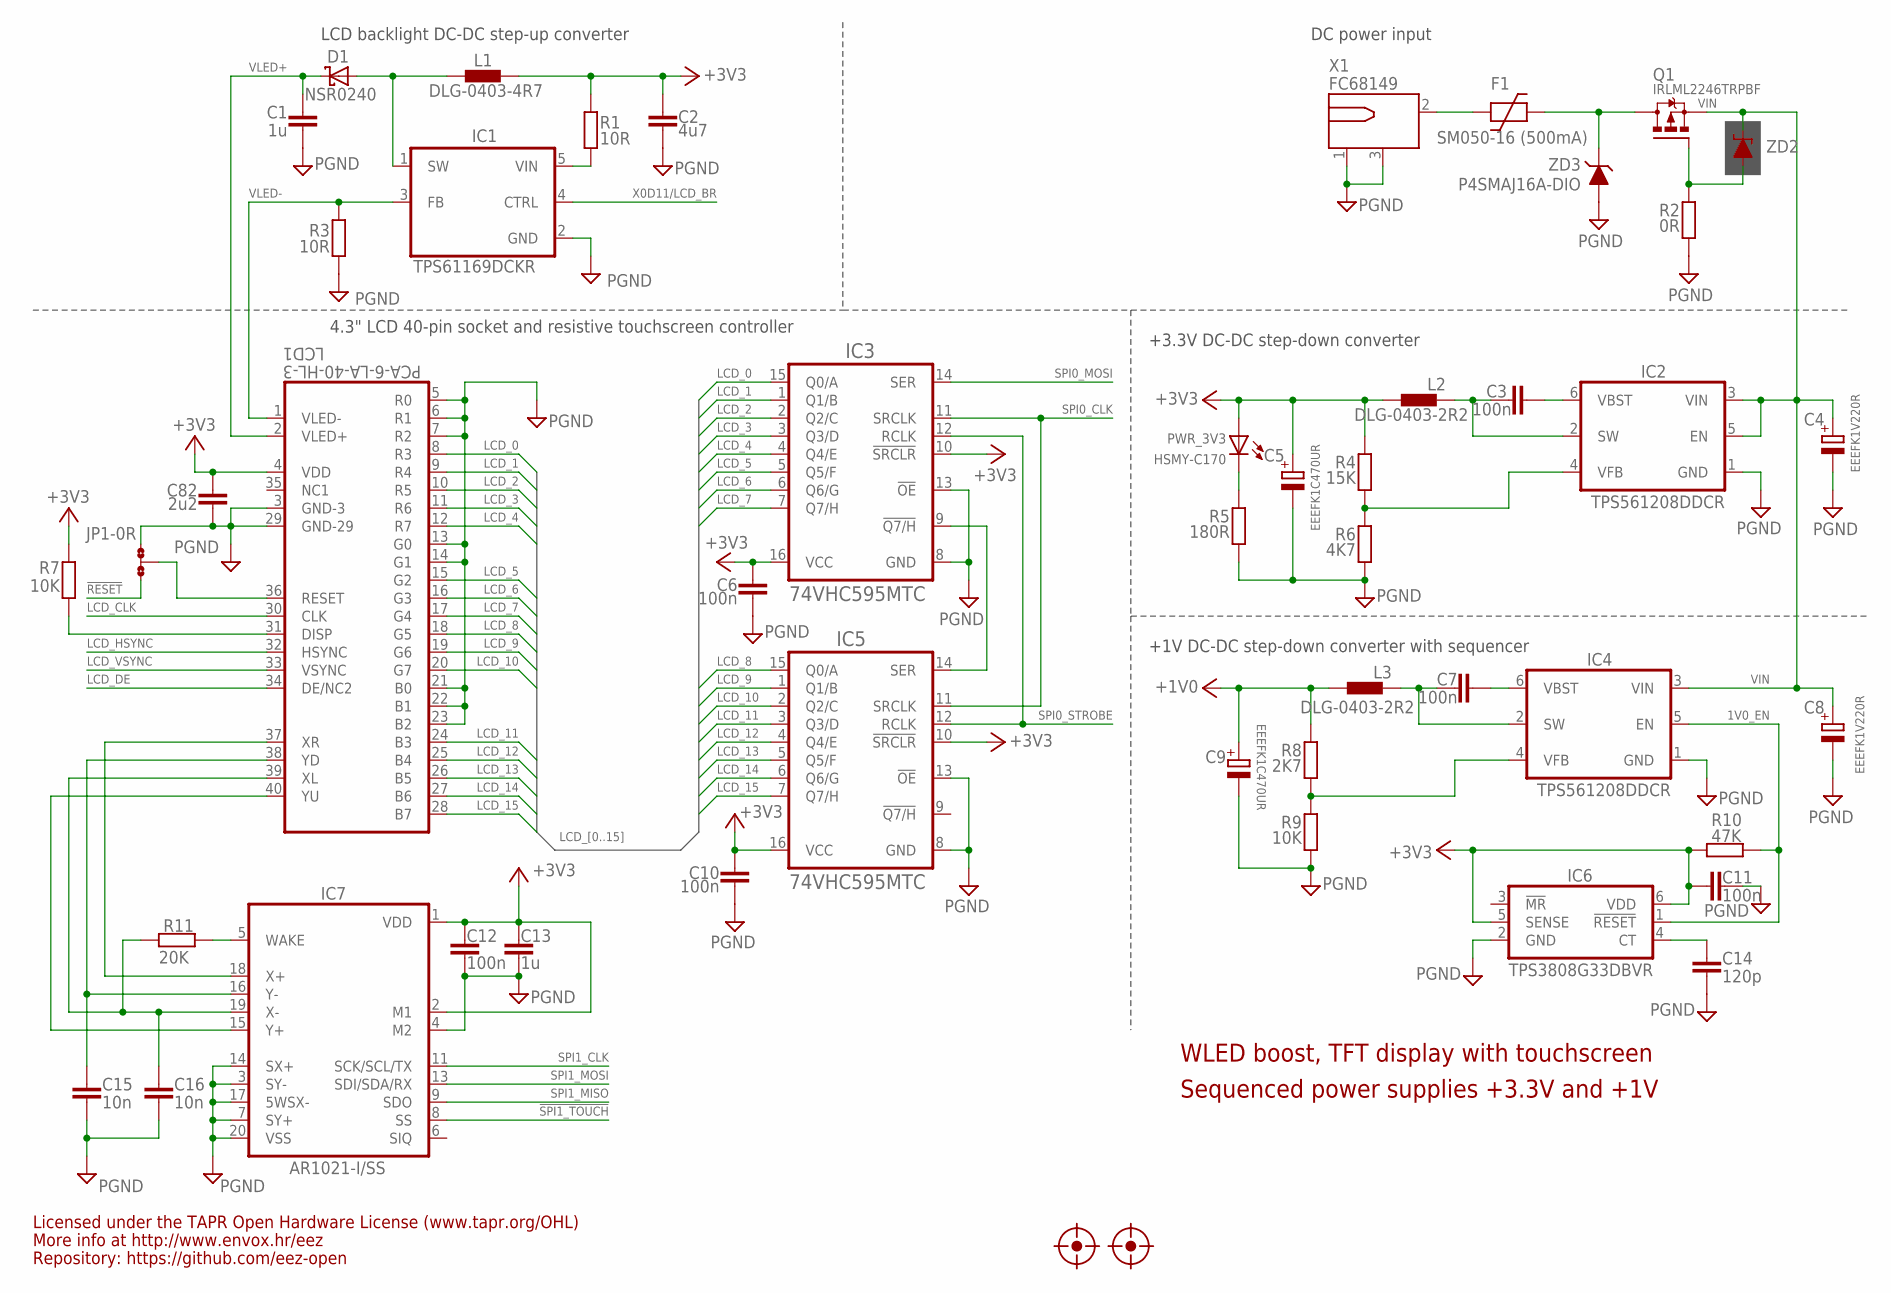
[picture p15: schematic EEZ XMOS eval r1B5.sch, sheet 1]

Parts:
C1, C13: 1u; C0805
C2: 4u7; C1206
C3, C6, C7, C10, C11, C12: 100n; C0603
C4: EEEFK1V220R; CAPAE530X610N
C5, C9: EEEFK1C470UR; CAPAE530X610N; TOLERANCE ±20 %; VOLTAGERATING 35V; MPN EEE-FK1V100R
C8: EEEFK1V220R; CAPAE530X610N; TOLERANCE ±20 %; VOLTAGERATING 35V; MPN EEE-FK1V100R
C14: 120p; C0805
C15, C16: 10n; C0805
C82: 2u2; C0805
D1: NSR0240; SOD123
F1: SM050-16 (500mA); F1210
FM1, FM2: FIDUCIAL_2; FIDUCIAL_DUAL
IC1: TPS61169DCKR; DCK0005A_N
IC2, IC4: TPS561208DDCR; DBV6
IC3, IC5: 74VHC595MTC; PW(R-PDSO-G16)
IC6: TPS3808G33DBVR; DBV6
IC7: AR1021-I/SS; SOP65P780X200-20N
JP1: 0R-JUMPA; A0R-JMP
L1: DLG-0403-4R7; DE0403
L2, L3: DLG-0403-2R2; DE0403
LCD1: PCA-6-LA-40-HL-3; FPC_40
PWR_3V3: HSMY-C170; LED_0805
Q1: IRLML2246TRPBF; SOT95P237X112-3N
R1, R3: 10R; R1206
R2: 0R; R0805
R4: 15K; R0805
R5: 180R; R0805
R6: 4K7; R0805
R7, R9: 10K; R0805
R8: 2K7; R0805
R10: 47K; R0805
R11: 20K; R0805
X1: FC68149; DC-21MM
ZD2: ZENER-DIODESOD323; SOD323-W
ZD3: P4SMAJ16A-DIO; DO214AC

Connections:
1V0_EN: IC4.5 (EN), IC6.1 (!RESET), R10.1
!RESET: JP1.1; also elsewhere on the board
!SPI1_TOUCH: IC7.8 (SS); also elsewhere on the board
+1V0: C9.1, L3.2, R8.2; also elsewhere on the board
+1V0_SW: C7.1, IC4.2 (SW), L3.1
+3V3: C2.1, C5.1, C6.2, C10.2, C11.2, C12.2, C13.2, C82.1, IC3.10 (!SRCLR), IC3.16 (VCC), IC5.10 (!SRCLR), IC5.16 (VCC), IC6.5 (SENSE), IC6.6 (VDD), IC7.1 (VDD), IC7.2 (M1), L1.1, L2.2, LCD1.4 (VDD), PWR_3V3.A, R1.1, R4.2, R7.2, R10.2; also elsewhere on the board
+3V3_SW: C3.1, IC2.2 (SW), L2.1
GND: C1.2, C2.2, C4.2, C5.2, C6.1, C8.2, C9.2, C10.1, C11.1, C12.1, C13.1, C14.2, C15.2, C16.2, C82.2, IC1.2 (GND), IC2.1 (GND), IC3.8 (GND), IC3.13 (!OE), IC4.1 (GND), IC5.8 (GND), IC5.13 (!OE), IC6.2 (GND), IC7.3 (SY-), IC7.4 (M2), IC7.7 (SY+), IC7.14 (SX+), IC7.17 (5WSX-), IC7.20 (VSS), JP1.3, LCD1.3 (GND-3), LCD1.5 (R0), LCD1.6 (R1), LCD1.7 (R2), LCD1.13 (G0), LCD1.14 (G1), LCD1.21 (B0), LCD1.22 (B1), LCD1.23 (B2), LCD1.29 (GND-29), R2.1, R3.2, R5.1, R6.1, R9.1, X1.1, X1.3, ZD3.A; also elsewhere on the board
LCD_0: IC3.15 (Q0/A), LCD1.8 (R3)
LCD_1: IC3.1 (Q1/B), LCD1.9 (R4)
LCD_2: IC3.2 (Q2/C), LCD1.10 (R5)
LCD_3: IC3.3 (Q3/D), LCD1.11 (R6)
LCD_4: IC3.4 (Q4/E), LCD1.12 (R7)
LCD_5: IC3.5 (Q5/F), LCD1.15 (G2)
LCD_6: IC3.6 (Q6/G), LCD1.16 (G3)
LCD_7: IC3.7 (Q7/H), LCD1.17 (G4)
LCD_8: IC5.15 (Q0/A), LCD1.18 (G5)
LCD_9: IC5.1 (Q1/B), LCD1.19 (G6)
LCD_10: IC5.2 (Q2/C), LCD1.20 (G7)
LCD_11: IC5.3 (Q3/D), LCD1.24 (B3)
LCD_12: IC5.4 (Q4/E), LCD1.25 (B4)
LCD_13: IC5.5 (Q5/F), LCD1.26 (B5)
LCD_14: IC5.6 (Q6/G), LCD1.27 (B6)
LCD_15: IC5.7 (Q7/H), LCD1.28 (B7)
LCD_CLK: LCD1.30 (CLK); also elsewhere on the board
LCD_DE: LCD1.34 (DE/NC2); also elsewhere on the board
LCD_HSYNC: LCD1.32 (HSYNC); also elsewhere on the board
LCD_VSYNC: LCD1.33 (VSYNC); also elsewhere on the board
unnamed: PWR_3V3.C, R5.2
unnamed: IC7.15 (Y+), LCD1.40 (YU)
unnamed: C16.1, IC7.19 (X-), LCD1.39 (XL), R11.2
unnamed: IC7.18 (X+), LCD1.37 (XR)
unnamed: Q1.1 (G), R2.2, ZD2.A
unnamed: IC7.5 (WAKE), R11.1
unnamed: F1.1, X1.2
unnamed: JP1.2, LCD1.36 (RESET)
unnamed: IC2.4 (VFB), R4.1, R6.2
unnamed: IC1.5 (VIN), R1.2
unnamed: C3.2, IC2.6 (VBST)
unnamed: IC3.9 (!Q7/H), IC5.14 (SER)
unnamed: IC4.4 (VFB), R8.1, R9.2
unnamed: C7.2, IC4.6 (VBST)
unnamed: C15.1, IC7.16 (Y-), LCD1.38 (YD)
unnamed: C14.1, IC6.4 (CT)
unnamed: LCD1.31 (DISP), R7.1
PMOS_D: F1.2, Q1.3 (D), ZD3.C
SPI0_CLK: IC3.11 (SRCLK), IC5.11 (SRCLK); also elsewhere on the board
SPI0_MOSI: IC3.14 (SER); also elsewhere on the board
SPI0_STROBE: IC3.12 (RCLK), IC5.12 (RCLK); also elsewhere on the board
SPI1_CLK: IC7.11 (SCK/SCL/TX); also elsewhere on the board
SPI1_MISO: IC7.9 (SDO); also elsewhere on the board
SPI1_MOSI: IC7.13 (SDI/SDA/RX); also elsewhere on the board
SW_WLED: D1.A, IC1.1 (SW), L1.2
VIN: C4.1, C8.1, IC2.3 (VIN), IC2.5 (EN), IC4.3 (VIN), Q1.2 (S), ZD2.C; also elsewhere on the board
VLED+: C1.1, D1.C, LCD1.2 (VLED+)
VLED-: IC1.3 (FB), LCD1.1 (VLED-), R3.1
X0D11/LCD_BR: IC1.4 (CTRL); also elsewhere on the board

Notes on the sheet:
Licensed under the TAPR Open Hardware License (www.tapr.org/OHL)
Repository: https://github.com/eez-open
More info at http://www.envox.hr/eez
Sequenced power supplies +3.3V and +1V
4.3" LCD 40-pin socket and resistive touchscreen controller
LCD backlight DC-DC step-up converter
WLED boost, TFT display with touchscreen
DC power input
+3.3V DC-DC step-down converter
+1V DC-DC step-down converter with sequencer

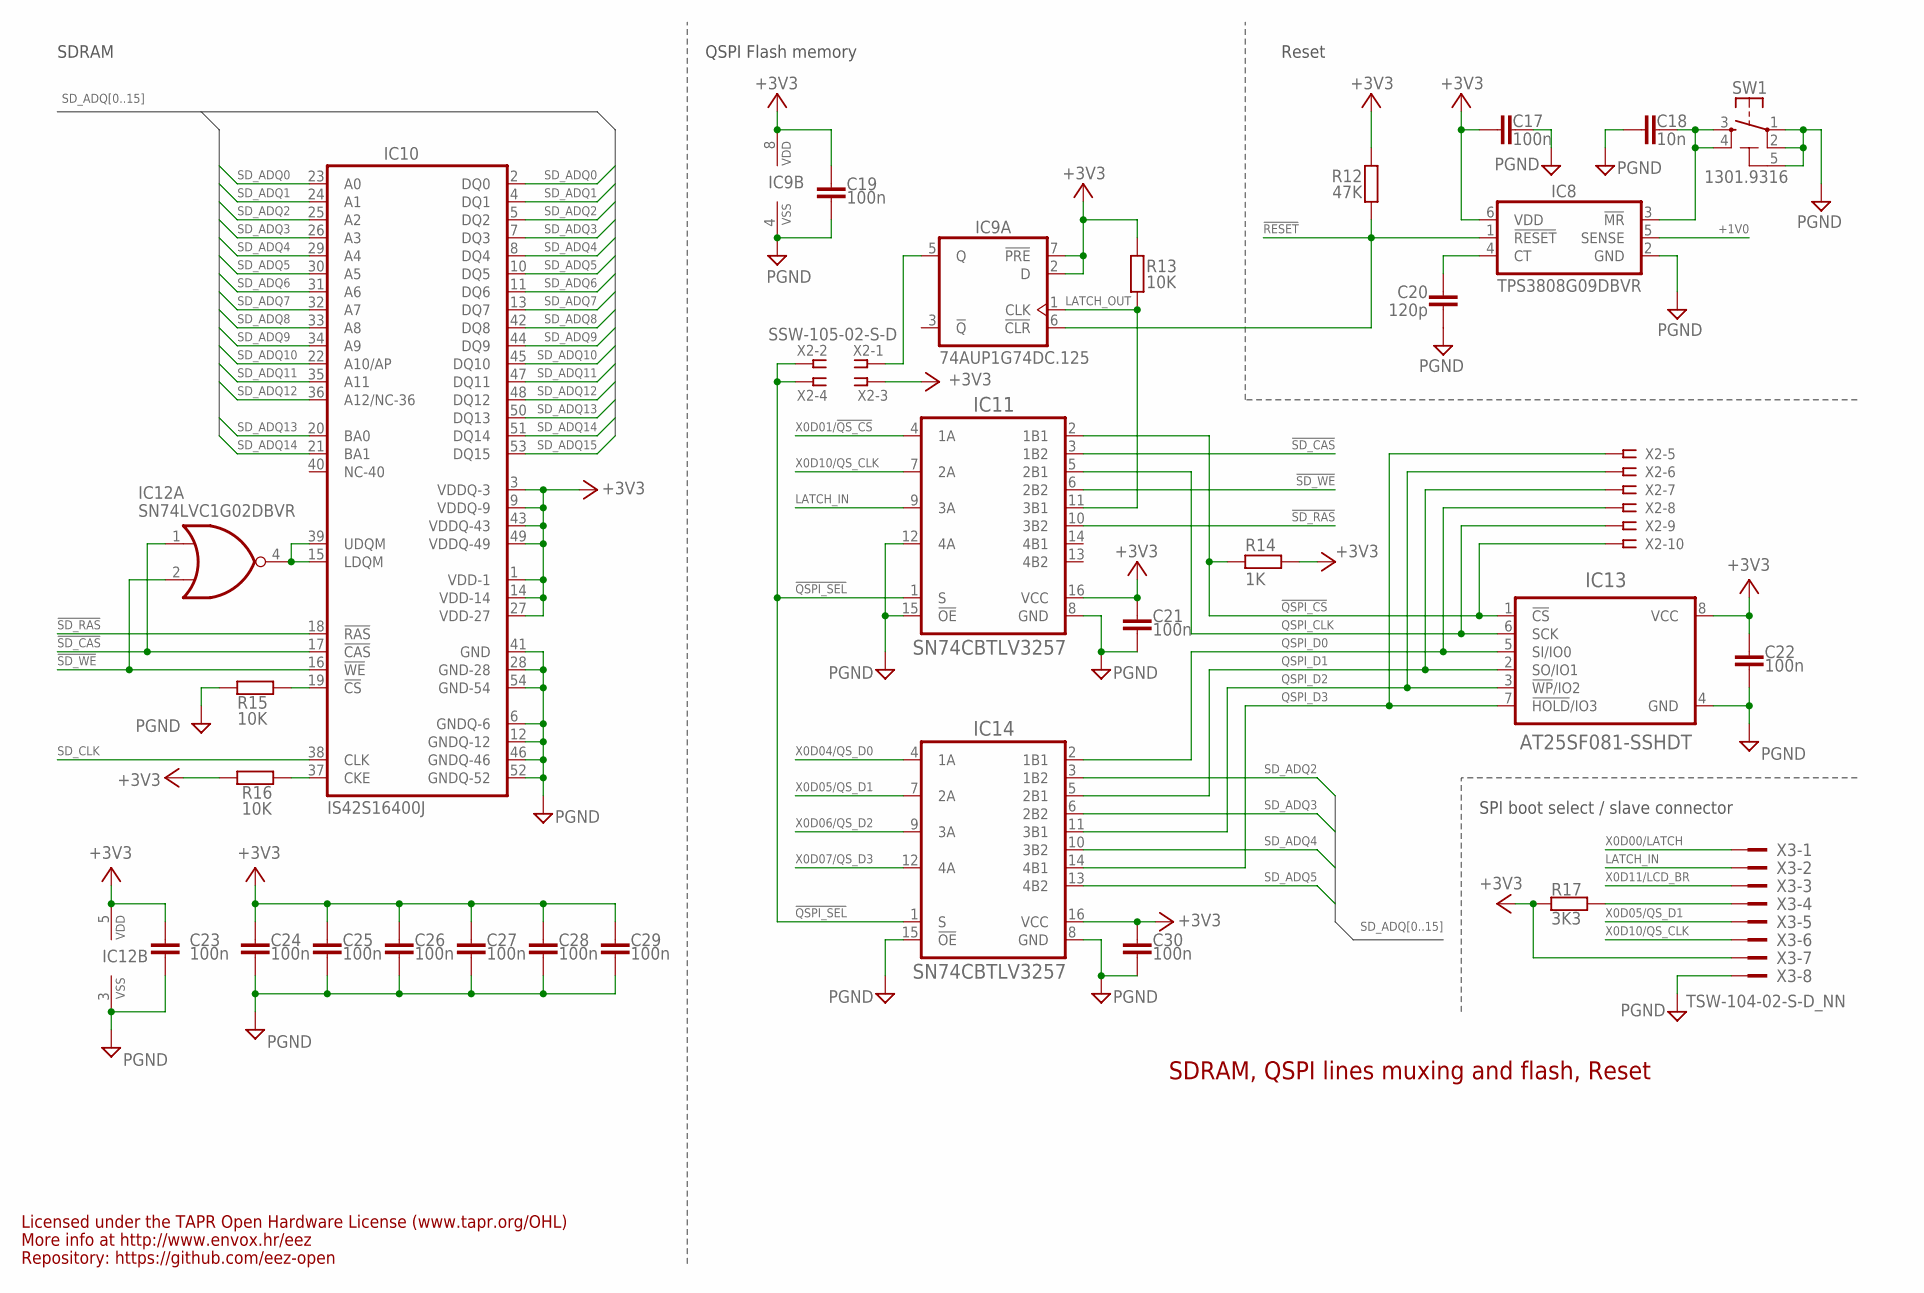
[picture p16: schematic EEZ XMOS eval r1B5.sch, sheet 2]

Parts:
C17, C19, C21, C22, C23, C24, C25, C26, C27, C28, C29, C30: 100n; C0603
C18: 10n; C0805
C20: 120p; C0805
IC8: TPS3808G09DBVR; DBV6; MANUFACTURER_PART_NUMBER tps3808g01_dbv_6
IC9: 74AUP1G74DC.125; DCU8
IC10: IS42S16400J; TSOPII-54
IC11, IC14: SN74CBTLV3257; PW(R-PDSO-G16)
IC12: SN74LVC1G02DBVR; DBV5
IC13: AT25SF081-SSHDT; SOIC127P600X175-8N
R12: 47K; R0805
R13, R15, R16: 10K; R0805
R14: 1K; R0805
R17: 3K3; R0805
SW1: 1301.9316; TACTM-6XN
X2: SSW-105-02-S-D
X3: TSW-104-02-S-D_NN; TSW-104-02-S-D-NONUM

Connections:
!QSPI_CS: IC11.2 (1B1), IC13.1 (!CS), R14.2, X2.10
!QSPI_SEL: IC11.1 (S), IC14.1 (S), X2.2, X2.4
!RESET: IC8.1 (!RESET), IC9.6 (!CLR), R12.2; also elsewhere on the board
!SD_CAS: IC10.17 (!CAS), IC11.3 (1B2), IC12.1 (A)
!SD_RAS: IC10.18 (!RAS), IC11.10 (3B2)
!SD_WE: IC10.16 (!WE), IC11.6 (2B2), IC12.2 (B)
+1V0: IC8.5 (SENSE); also elsewhere on the board
+3V3: C17.1, C19.1, C21.1, C22.1, C23.1, C24.1, C25.1, C26.1, C27.1, C28.1, C29.1, C30.1, IC8.6 (VDD), IC9.2 (D), IC9.7 (!PRE), IC9.8 (VDD), IC10.1 (VDD-1), IC10.3 (VDDQ-3), IC10.9 (VDDQ-9), IC10.14 (VDD-14), IC10.27 (VDD-27), IC10.43 (VDDQ-43), IC10.49 (VDDQ-49), IC11.16 (VCC), IC12.5 (VDD), IC13.8 (VCC), IC14.16 (VCC), R12.1, R13.1, R14.1, R16.2, R17.2, X2.3, X3.7; also elsewhere on the board
GND: C17.2, C18.1, C19.2, C20.2, C21.2, C22.2, C23.2, C24.2, C25.2, C26.2, C27.2, C28.2, C29.2, C30.2, IC8.2 (GND), IC9.4 (VSS), IC10.6 (GNDQ-6), IC10.12 (GNDQ-12), IC10.28 (GND-28), IC10.41 (GND), IC10.46 (GNDQ-46), IC10.52 (GNDQ-52), IC10.54 (GND-54), IC11.8 (GND), IC11.12 (4A), IC11.15 (!OE), IC12.3 (VSS), IC13.4 (GND), IC14.8 (GND), IC14.15 (!OE), R15.2, SW1.1, SW1.2, SW1.5 (5-GND), X3.8; also elsewhere on the board
LATCH_IN: IC11.9 (3A), X3.2
LATCH_OUT: IC9.1 (CLK), IC11.11 (3B1), R13.2
unnamed: R17.1, X3.4
unnamed: IC10.19 (!CS), R15.1
unnamed: IC10.15 (LDQM), IC10.39 (UDQM), IC12.4 (Y)
unnamed: IC10.37 (CKE), R16.1
unnamed: C20.1, IC8.4 (CT)
unnamed: C18.2, IC8.3 (!MR), SW1.3, SW1.4
unnamed: IC9.5 (Q), X2.1
QSPI_CLK: IC11.5 (2B1), IC13.6 (SCK), X2.9
QSPI_D0: IC13.5 (SI/IO0), IC14.2 (1B1), X2.8
QSPI_D1: IC13.2 (SO/IO1), IC14.5 (2B1), X2.7
QSPI_D2: IC13.3 (!WP!/IO2), IC14.11 (3B1), X2.6
QSPI_D3: IC13.7 (!HOLD!/IO3), IC14.14 (4B1), X2.5
SD_ADQ0: IC10.2 (DQ0), IC10.23 (A0); also elsewhere on the board
SD_ADQ1: IC10.4 (DQ1), IC10.24 (A1); also elsewhere on the board
SD_ADQ2: IC10.5 (DQ2), IC10.25 (A2), IC14.3 (1B2)
SD_ADQ3: IC10.7 (DQ3), IC10.26 (A3), IC14.6 (2B2)
SD_ADQ4: IC10.8 (DQ4), IC10.29 (A4), IC14.10 (3B2)
SD_ADQ5: IC10.10 (DQ5), IC10.30 (A5), IC14.13 (4B2)
SD_ADQ6: IC10.11 (DQ6), IC10.31 (A6); also elsewhere on the board
SD_ADQ7: IC10.13 (DQ7), IC10.32 (A7); also elsewhere on the board
SD_ADQ8: IC10.33 (A8), IC10.42 (DQ8); also elsewhere on the board
SD_ADQ9: IC10.34 (A9), IC10.44 (DQ9); also elsewhere on the board
SD_ADQ10: IC10.22 (A10/AP), IC10.45 (DQ10); also elsewhere on the board
SD_ADQ11: IC10.35 (A11), IC10.47 (DQ11); also elsewhere on the board
SD_ADQ12: IC10.36 (A12/NC-36), IC10.48 (DQ12); also elsewhere on the board
SD_ADQ13: IC10.20 (BA0), IC10.50 (DQ13); also elsewhere on the board
SD_ADQ14: IC10.21 (BA1), IC10.51 (DQ14); also elsewhere on the board
SD_ADQ15: IC10.53 (DQ15); also elsewhere on the board
SD_CLK: IC10.38 (CLK); also elsewhere on the board
X0D00/LATCH: X3.1; also elsewhere on the board
X0D01/!QS_CS: IC11.4 (1A); also elsewhere on the board
X0D04/QS_D0: IC14.4 (1A); also elsewhere on the board
X0D05/QS_D1: IC14.7 (2A), X3.5; also elsewhere on the board
X0D06/QS_D2: IC14.9 (3A); also elsewhere on the board
X0D07/QS_D3: IC14.12 (4A); also elsewhere on the board
X0D10/QS_CLK: IC11.7 (2A), X3.6; also elsewhere on the board
X0D11/LCD_BR: X3.3; also elsewhere on the board

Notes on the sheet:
Licensed under the TAPR Open Hardware License (www.tapr.org/OHL)
Repository: https://github.com/eez-open
More info at http://www.envox.hr/eez
SDRAM, QSPI lines muxing and flash, Reset
QSPI Flash memory
SDRAM
Reset
SPI boot select / slave connector

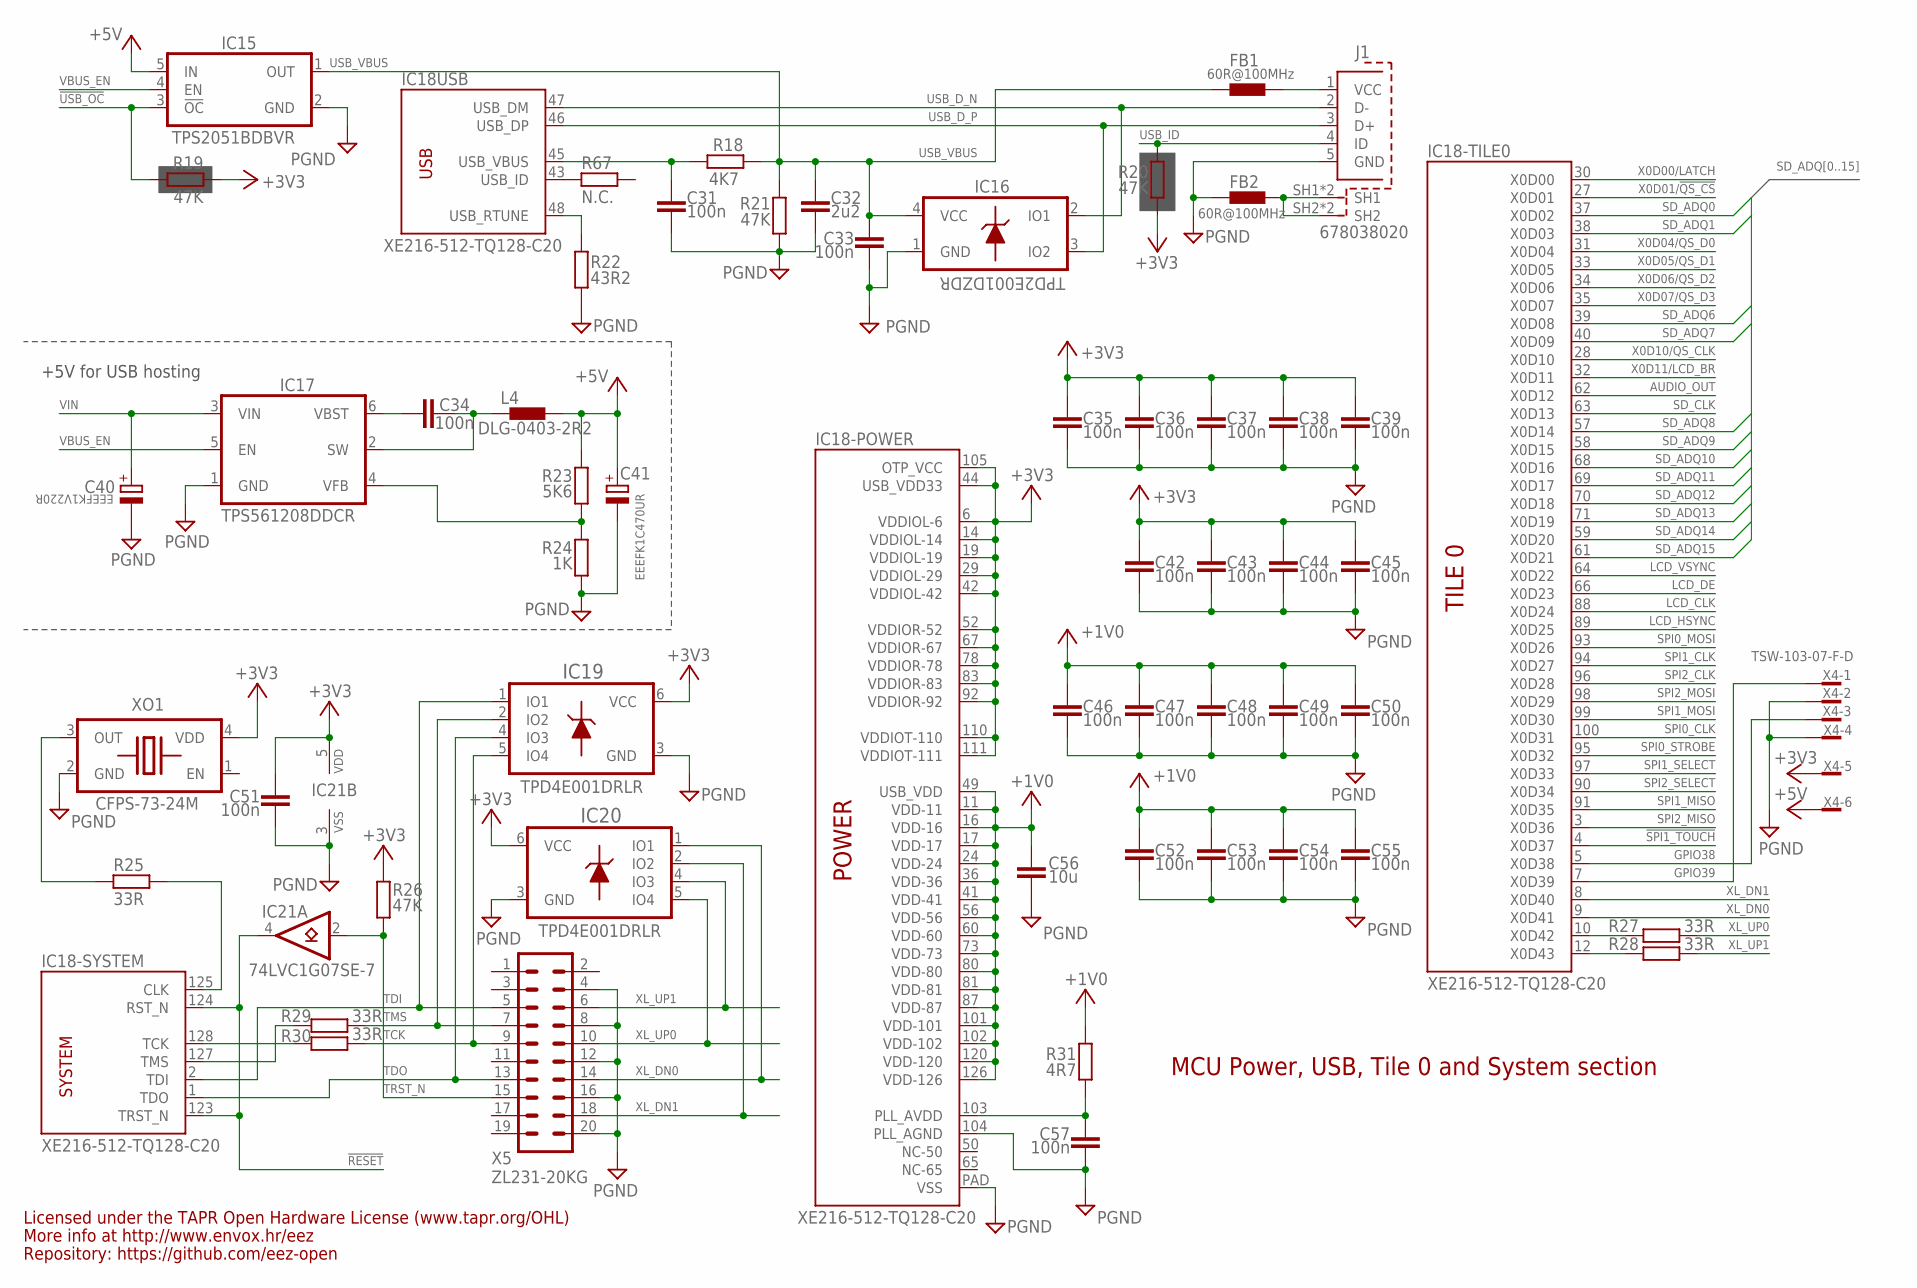
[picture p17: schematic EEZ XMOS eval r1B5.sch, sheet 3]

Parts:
C31, C33, C34, C35, C36, C37, C38, C39, C42, C43, C44, C45, C46, C47, C48, C49, C50, C51, C52, C53, C54, C55, C57: 100n; C0603
C32: 2u2; C0805
C40: EEEFK1V220R; CAPAE530X610N
C41: EEEFK1C470UR; CAPAE530X610N; TOLERANCE ±20 %; VOLTAGERATING 35V; MPN EEE-FK1V100R
C56: 10u; C1210
FB1, FB2: 60R@100MHz; BEAD0603
IC15: TPS2051BDBVR; DBV5
IC16: TPD2E001DZDR; SOP192P292X122-4N
IC17: TPS561208DDCR; DBV6
IC18: XE216-512-TQ128-C20; TQ128
IC19, IC20: TPD4E001DRLR; DRL6
IC21: 74LVC1G07SE-7; DCK5
J1: 678038020
L4: DLG-0403-2R2; DE0403
R18: 4K7; R0805
R19, R20, R21, R26: 47K; R0805
R22: 43R2; R0805
R23: 5K6; R0805
R24: 1K; R0805
R25, R27, R28, R29, R30: 33R; R0603
R31: 4R7; R0805
R67: N.C.; R0805
X4: TSW-103-07-F-D
X5: ZL231-20KG; ML20L
XO1: CFPS-73-24M; 12SMX(C)

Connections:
!RESET: IC18.123 (TRST_N), IC18.124 (RST_N), IC21.4 (Y); also elsewhere on the board
!SPI1_TOUCH: IC18.4 (X0D37); also elsewhere on the board
!USB_OC: IC15.3 (!OC), R19.1; also elsewhere on the board
+1V0: C46.1, C47.1, C48.1, C49.1, C50.1, C52.1, C53.1, C54.1, C55.1, C56.1, IC18.11 (VDD-11), IC18.16 (VDD-16), IC18.17 (VDD-17), IC18.24 (VDD-24), IC18.36 (VDD-36), IC18.41 (VDD-41), IC18.49 (USB_VDD), IC18.56 (VDD-56), IC18.60 (VDD-60), IC18.73 (VDD-73), IC18.80 (VDD-80), IC18.81 (VDD-81), IC18.87 (VDD-87), IC18.101 (VDD-101), IC18.102 (VDD-102), IC18.120 (VDD-120), IC18.126 (VDD-126), R31.1; also elsewhere on the board
+3V3: C35.1, C36.1, C37.1, C38.1, C39.1, C42.1, C43.1, C44.1, C45.1, C51.1, IC18.6 (VDDIOL-6), IC18.14 (VDDIOL-14), IC18.19 (VDDIOL-19), IC18.29 (VDDIOL-29), IC18.42 (VDDIOL-42), IC18.44 (USB_VDD33), IC18.52 (VDDIOR-52), IC18.67 (VDDIOR-67), IC18.78 (VDDIOR-78), IC18.83 (VDDIOR-83), IC18.92 (VDDIOR-92), IC18.105 (OTP_VCC), IC18.110 (VDDIOT-110), IC18.111 (VDDIOT-111), IC19.6 (VCC), IC20.6 (VCC), IC21.5 (VDD), R19.2, R20.1, R26.1, X4.5, XO1.4 (VDD); also elsewhere on the board
+5V: C41.1, IC15.5 (IN), L4.2, R23.2, X4.6
+5V_SW: C34.1, IC17.2 (SW), L4.1
AUDIO_OUT: IC18.62 (X0D12); also elsewhere on the board
GND: C31.2, C32.2, C33.1, C35.2, C36.2, C37.2, C38.2, C39.2, C40.2, C41.2, C42.2, C43.2, C44.2, C45.2, C46.2, C47.2, C48.2, C49.2, C50.2, C51.2, C52.2, C53.2, C54.2, C55.2, C56.2, C57.2, FB2.P$1 (1), IC15.2 (GND), IC16.1 (GND), IC17.1 (GND), IC18.104 (PLL_AGND), IC18.PAD (VSS), IC19.3 (GND), IC20.3 (GND), IC21.3 (VSS), J1.5 (GND), R21.2, R22.2, R24.1, X4.2, X4.4, X5.4, X5.8, X5.12, X5.16, X5.20, XO1.2 (GND); also elsewhere on the board
GPIO38: IC18.5 (X0D38), X4.3
GPIO39: IC18.7 (X0D39), X4.1
LCD_CLK: IC18.88 (X0D24); also elsewhere on the board
LCD_DE: IC18.66 (X0D23); also elsewhere on the board
LCD_HSYNC: IC18.89 (X0D25); also elsewhere on the board
LCD_VSYNC: IC18.64 (X0D22); also elsewhere on the board
unnamed: IC18.10 (X0D42), R27.1
unnamed: IC18.12 (X0D43), R28.1
unnamed: IC18.125 (CLK), R25.2
unnamed: IC18.43 (USB_ID), R67.1
unnamed: C57.1, IC18.103 (PLL_AVDD), R31.2
unnamed: FB2.P$2 (2), J1.SH1, J1.SH1.1 (SH1), J1.SH2, J1.SH2.2 (SH2)
unnamed: IC18.48 (USB_RTUNE), R22.1
unnamed: C31.1, IC18.45 (USB_VBUS), R18.2
unnamed: IC18.127 (TMS), R29.1
unnamed: IC18.128 (TCK), R30.1
unnamed: IC17.4 (VFB), R23.1, R24.2
unnamed: FB1.P$2 (2), J1.1 (VCC)
unnamed: C34.2, IC17.6 (VBST)
unnamed: R25.1, XO1.3 (OUT)
SD_ADQ0: IC18.37 (X0D02); also elsewhere on the board
SD_ADQ1: IC18.38 (X0D03); also elsewhere on the board
SD_ADQ6: IC18.39 (X0D08); also elsewhere on the board
SD_ADQ7: IC18.40 (X0D09); also elsewhere on the board
SD_ADQ8: IC18.57 (X0D14); also elsewhere on the board
SD_ADQ9: IC18.58 (X0D15); also elsewhere on the board
SD_ADQ10: IC18.68 (X0D16); also elsewhere on the board
SD_ADQ11: IC18.69 (X0D17); also elsewhere on the board
SD_ADQ12: IC18.70 (X0D18); also elsewhere on the board
SD_ADQ13: IC18.71 (X0D19); also elsewhere on the board
SD_ADQ14: IC18.59 (X0D20); also elsewhere on the board
SD_ADQ15: IC18.61 (X0D21); also elsewhere on the board
SD_CLK: IC18.63 (X0D13); also elsewhere on the board
SPI0_CLK: IC18.100 (X0D31); also elsewhere on the board
SPI0_MOSI: IC18.93 (X0D26); also elsewhere on the board
SPI0_STROBE: IC18.95 (X0D32); also elsewhere on the board
SPI1_CLK: IC18.94 (X0D27); also elsewhere on the board
SPI1_MISO: IC18.91 (X0D35); also elsewhere on the board
SPI1_MOSI: IC18.99 (X0D30); also elsewhere on the board
SPI1_SELECT: IC18.97 (X0D33); also elsewhere on the board
SPI2_CLK: IC18.96 (X0D28); also elsewhere on the board
SPI2_MISO: IC18.3 (X0D36); also elsewhere on the board
SPI2_MOSI: IC18.98 (X0D29); also elsewhere on the board
SPI2_SELECT: IC18.90 (X0D34); also elsewhere on the board
TCK: IC19.5 (IO4), R30.2, X5.9
TDI: IC18.2 (TDI), IC19.1 (IO1), X5.5
TDO: IC18.1 (TDO), IC19.4 (IO3), X5.13
TMS: IC19.2 (IO2), R29.2, X5.7
TRST_N: IC21.2 (A), R26.2, X5.15
USB_D_N: IC16.2 (IO1), IC18.47 (USB_DM), J1.2 (D-)
USB_D_P: IC16.3 (IO2), IC18.46 (USB_DP), J1.3 (D+)
USB_ID: J1.4 (ID), R20.2; also elsewhere on the board
USB_VBUS: C32.1, C33.2, FB1.P$1 (1), IC15.1 (OUT), IC16.4 (VCC), R18.1, R21.1
VBUS_EN: IC15.4 (EN), IC17.5 (EN); also elsewhere on the board
VIN: C40.1, IC17.3 (VIN); also elsewhere on the board
X0D00/LATCH: IC18.30 (X0D00); also elsewhere on the board
X0D01/!QS_CS: IC18.27 (X0D01); also elsewhere on the board
X0D04/QS_D0: IC18.31 (X0D04); also elsewhere on the board
X0D05/QS_D1: IC18.33 (X0D05); also elsewhere on the board
X0D06/QS_D2: IC18.34 (X0D06); also elsewhere on the board
X0D07/QS_D3: IC18.35 (X0D07); also elsewhere on the board
X0D10/QS_CLK: IC18.28 (X0D10); also elsewhere on the board
X0D11/LCD_BR: IC18.32 (X0D11); also elsewhere on the board
XL_DN0: IC18.9 (X0D41), IC20.1 (IO1), X5.14
XL_DN1: IC18.8 (X0D40), IC20.2 (IO2), X5.18
XL_UP0: IC20.5 (IO4), R27.2, X5.10
XL_UP1: IC20.4 (IO3), R28.2, X5.6

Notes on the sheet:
Licensed under the TAPR Open Hardware License (www.tapr.org/OHL)
Repository: https://github.com/eez-open
More info at http://www.envox.hr/eez
MCU Power, USB, Tile 0 and System section
+5V for USB hosting

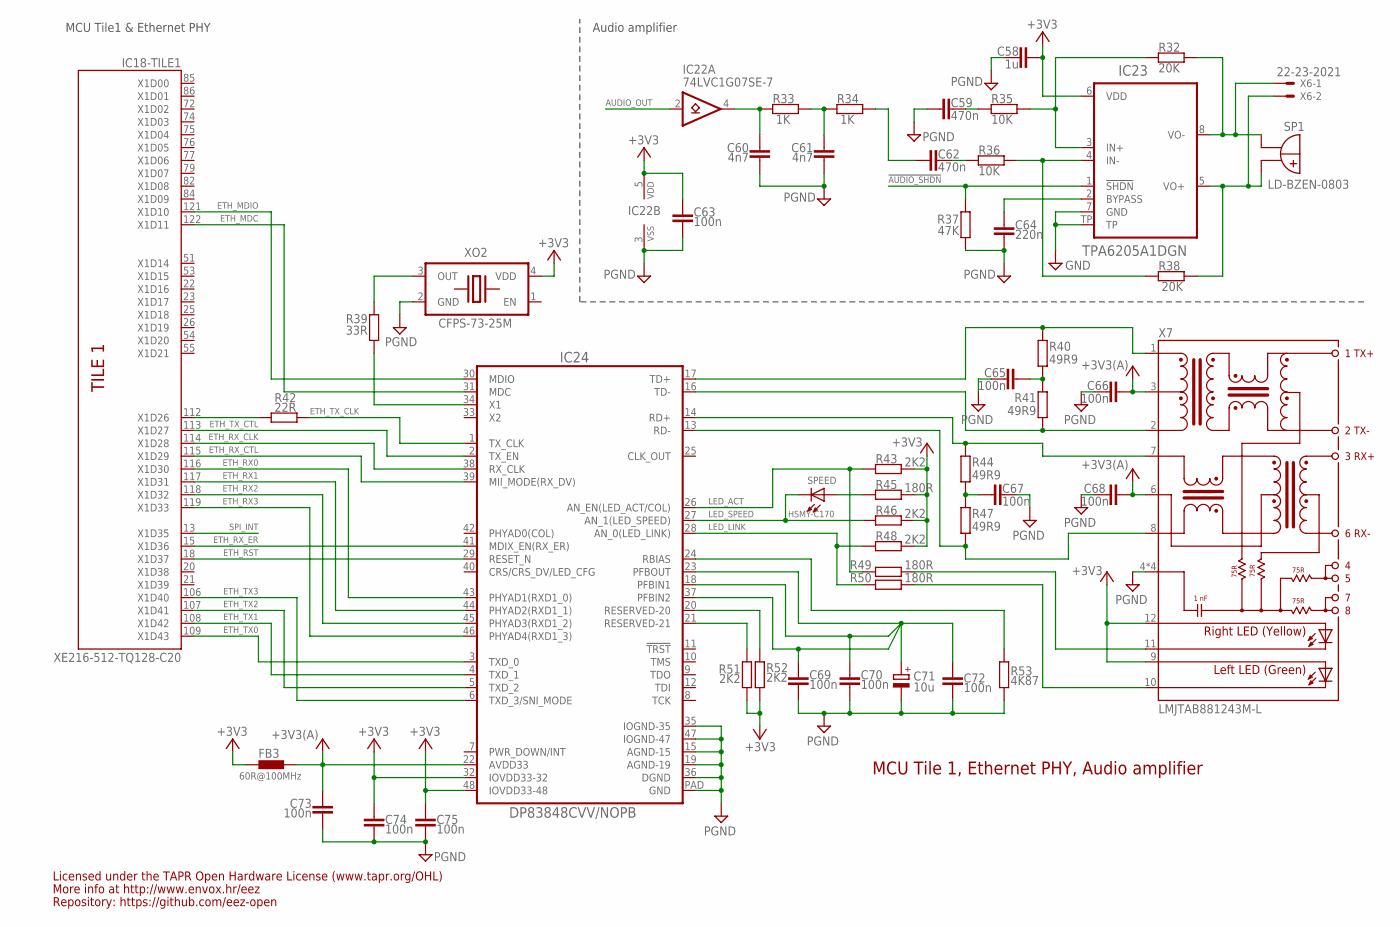
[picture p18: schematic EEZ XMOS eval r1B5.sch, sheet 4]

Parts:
C58: 1u; C0805
C59, C62: 470n; C0805
C60, C61: 4n7; C0805
C63, C65, C66, C67, C68, C69, C70, C72, C73, C74, C75: 100n; C0603
C64: 220n; C0805
C71: 10u; EC1206
FB3: 60R@100MHz; BEAD0603
IC18: XE216-512-TQ128-C20; TQ128
IC22: 74LVC1G07SE-7; DCK5
IC23: TPA6205A1DGN; SOP65P490X110-9N
IC24: DP83848CVV/NOPB; PT48+PAD
R32, R38: 20K; R0805
R33, R34: 1K; R0805
R35, R36: 10K; R0805
R37: 47K; R0805
R39: 33R; R0603
R40, R41, R44, R47: 49R9; R0805
R42: 22R; R0805
R43, R46, R48, R51, R52: 2K2; R0805
R45, R49, R50: 180R; R0805
R53: 4K87; R0603
SP1: LD-BZEN-0803
SPEED: HSMY-C170; LED_0805
X6: 22-23-2021; MPN 22-23-2021
X7: LMJTAB881243M-L; RJ45-TRAFO-LED
XO2: CFPS-73-25M; 12SMX(C)

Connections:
!AUDIO_SHDN: IC23.1 (!SHDN), R37.1; also elsewhere on the board
+3V3: C58.2, C63.2, C74.1, C75.1, FB3.P$1 (1), IC22.5 (VDD), IC23.6 (VDD), IC24.32 (IOVDD33-32), IC24.48 (IOVDD33-48), R43.1, R45.1, R46.1, R48.1, R51.1, R52.1, X7.9 (GREEN-A), X7.12 (YELLOW_A), XO2.4 (VDD); also elsewhere on the board
+3V3(A): C66.2, C68.2, C73.1, FB3.P$2 (2), IC24.22 (AVDD33), X7.3 (CT), X7.6 (CR)
AUDIO_OUT: IC22.2 (A); also elsewhere on the board
ETH_MDC: IC18.122 (X1D11), IC24.31 (MDC)
ETH_MDIO: IC18.121 (X1D10), IC24.30 (MDIO)
ETH_RST: IC18.18 (X1D37), IC24.29 (RESET_N); also elsewhere on the board
ETH_RX0: IC18.116 (X1D30), IC24.43 (PHYAD1(RXD1_0))
ETH_RX1: IC18.117 (X1D31), IC24.44 (PHYAD2(RXD1_1))
ETH_RX2: IC18.118 (X1D32), IC24.45 (PHYAD3(RXD1_2))
ETH_RX3: IC18.119 (X1D33), IC24.46 (PHYAD4(RXD1_3))
ETH_RX_CLK: IC18.114 (X1D28), IC24.38 (RX_CLK)
ETH_RX_CTL: IC18.115 (X1D29), IC24.39 (MII_MODE(RX_DV))
ETH_RX_ER: IC18.15 (X1D36), IC24.41 (MDIX_EN(RX_ER))
ETH_TX0: IC18.109 (X1D43), IC24.3 (TXD_0)
ETH_TX1: IC18.108 (X1D42), IC24.4 (TXD_1)
ETH_TX2: IC18.107 (X1D41), IC24.5 (TXD_2)
ETH_TX3: IC18.106 (X1D40), IC24.6 (TXD_3/SNI_MODE)
ETH_TX_CLK: IC24.1 (TX_CLK), R42.2
ETH_TX_CTL: IC18.113 (X1D27), IC24.2 (TX_EN)
GND: C58.1, C59.2, C60.2, C61.2, C63.1, C64.1, C65.2, C66.1, C67.2, C68.1, C69.2, C70.2, C71.-, C72.2, C73.2, C74.2, C75.2, IC22.3 (VSS), IC23.7 (GND), IC23.TP, IC24.15 (AGND-15), IC24.19 (AGND-19), IC24.35 (IOGND-35), IC24.36 (DGND), IC24.47 (IOGND-47), IC24.PAD (GND), R37.2, R53.1, X7.4 (SH), X7.5 (SH), X7.SH1 (SH), X7.SH2 (SH), XO2.2 (GND); also elsewhere on the board
LED_ACT: IC24.26 (AN_EN(LED_ACT/COL)), R43.2, R49.2
LED_LINK: IC24.28 (AN_0(LED_LINK)), R48.2, R50.2
LED_SPEED: IC24.27 (AN_1(LED_SPEED)), R46.2, SPEED.C
unnamed: IC18.112 (X1D26), R42.1
unnamed: IC24.34 (X1), R39.2
unnamed: R49.1, X7.11 (YELLOW-C)
unnamed: R50.1, X7.10 (GREEN-C)
unnamed: R39.1, XO2.3 (OUT)
unnamed: IC23.5 (VO+), R38.1, SP1.+, X6.2
unnamed: IC24.24 (RBIAS), R53.2
unnamed: IC24.21 (RESERVED-21), R51.2
unnamed: IC24.20 (RESERVED-20), R52.2
unnamed: R45.2, SPEED.A
unnamed: C67.1, R44.1, R47.2
unnamed: C65.1, R40.1, R41.2
unnamed: IC23.8 (VO-), R32.1, SP1.-, X6.1
unnamed: IC23.4 (IN-), R36.1, R38.2
unnamed: IC23.3 (IN+), R32.2, R35.1
unnamed: C59.1, R35.2
unnamed: C64.2, IC23.2 (BYPASS)
unnamed: C62.1, R36.2
unnamed: C62.2, R34.1
unnamed: C61.1, R33.1, R34.2
unnamed: C60.1, IC22.4 (Y), R33.2
PFBOUT: C69.1, C70.1, C71.+, C72.1, IC24.18 (PFBIN1), IC24.23 (PFBOUT), IC24.37 (PFBIN2)
RD+: IC24.14 (RD+), R44.2, X7.7 (RD+)
RD-: IC24.13 (RD-), R47.1, X7.8 (RD-)
SPI_INT: IC18.13 (X1D35); also elsewhere on the board
TD+: IC24.17 (TD+), R40.2, X7.1 (TD+)
TD-: IC24.16 (TD-), R41.1, X7.2 (TD-)

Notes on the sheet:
Licensed under the TAPR Open Hardware License (www.tapr.org/OHL)
Repository: https://github.com/eez-open
More info at http://www.envox.hr/eez
MCU Tile 1, Ethernet PHY, Audio amplifier
Audio amplifier
MCU Tile1 & Ethernet PHY

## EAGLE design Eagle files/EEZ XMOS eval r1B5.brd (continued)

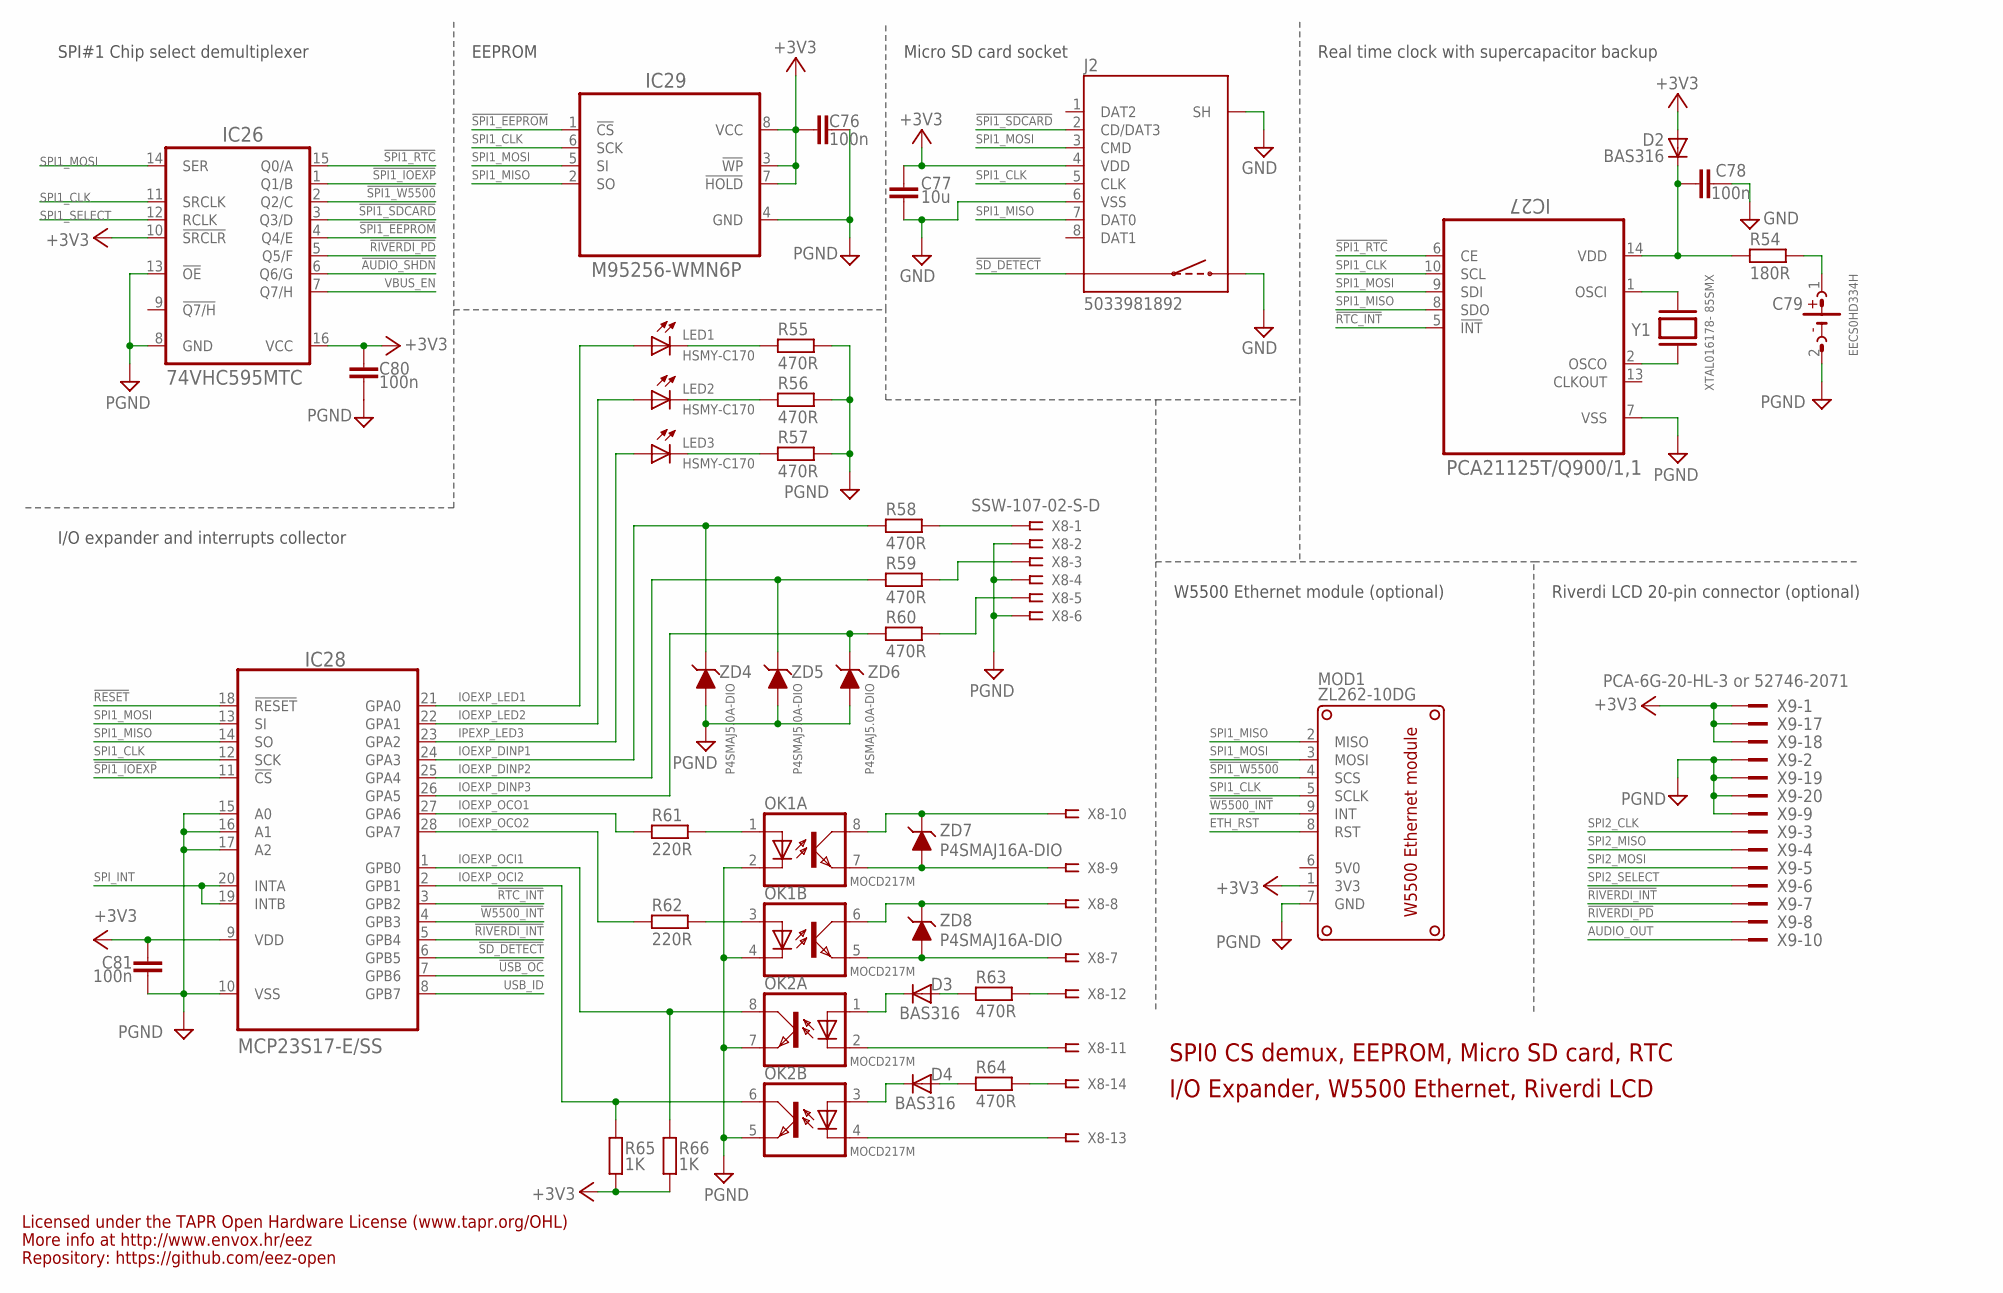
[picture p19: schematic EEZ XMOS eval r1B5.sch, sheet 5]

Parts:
C76, C78, C80, C81: 100n; C0603
C77: 10u; C1210
C79: EECS0HD334H; SG-R10MM
D2, D3, D4: BAS316; SOD323-W
IC26: 74VHC595MTC; PW(R-PDSO-G16)
IC27: PCA21125T/Q900/1,1; SOP65P640X120-14N
IC28: MCP23S17-E/SS; SOP65P780X200-28N
IC29: M95256-WMN6P; SOIC127P600X175-8N
J2: 5033981892
LED1, LED2, LED3: HSMY-C170; LED_0805
MOD1: ZL262-10DG; ETH_W5500_MODULE
OK1, OK2: MOCD217M; SO8-OPTO
R54: 180R; R0805
R55, R56, R57, R58, R59, R60, R63, R64: 470R; R0805
R61, R62: 220R; R0805
R65, R66: 1K; R0805
X8: SSW-107-02-S-D
X9: PCA-6G-20-HL-3 or 52746-2071; FPC-20_ROTATED
Y1: XTAL016178- 85SMX; 85SMX
ZD4, ZD5, ZD6: P4SMAJ5.0A-DIO; DO214AC
ZD7, ZD8: P4SMAJ16A-DIO; DO214AC

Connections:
5V0: MOD1.6 (5V0)
!AUDIO_SHDN: IC26.6 (Q6/G); also elsewhere on the board
!RESET: IC28.18 (!RESET); also elsewhere on the board
!RIVERDI_INT: IC28.5 (GPB4), X9.7
!RIVERDI_PD: IC26.5 (Q5/F), X9.8
!RTC_INT: IC27.5 (!INT), IC28.3 (GPB2)
!SD_DETECT: IC28.6 (GPB5), J2.SW1
!SPI1_EEPROM: IC26.4 (Q4/E), IC29.1 (!CS)
!SPI1_IOEXP: IC26.1 (Q1/B), IC28.11 (!CS)
!SPI1_RTC: IC26.15 (Q0/A), IC27.6 (CE)
!SPI1_SDCARD: IC26.3 (Q3/D), J2.2 (CD/DAT3)
!SPI1_W5500: IC26.2 (Q2/C), MOD1.4 (SCS)
!USB_OC: IC28.7 (GPB6); also elsewhere on the board
!W5500_INT: IC28.4 (GPB3), MOD1.9 (INT)
+3V3: C76.1, C77.1, C80.2, C81.1, D2.A, IC26.10 (!SRCLR), IC26.16 (VCC), IC28.9 (VDD), IC29.3 (!WP), IC29.7 (!HOLD), IC29.8 (VCC), J2.4 (VDD), MOD1.1 (3V3), R65.2, R66.2, X9.1, X9.17, X9.18; also elsewhere on the board
AUDIO_OUT: X9.10; also elsewhere on the board
ETH_RST: MOD1.8 (RST); also elsewhere on the board
GND: C76.2, C77.2, C78.1, C79.2 (-), C80.1, C81.2, IC26.8 (GND), IC26.13 (!OE), IC27.7 (VSS), IC28.10 (VSS), IC28.15 (A0), IC28.16 (A1), IC28.17 (A2), IC29.4 (GND), J2.6 (VSS), J2.S (SH), J2.SW2, MOD1.7 (GND), OK1.2 (C), OK1.4 (C), OK2.5 (EMIT), OK2.7 (EMIT), R55.1, R56.1, R57.1, X8.2, X8.4, X8.6, X9.2, X9.9, X9.19, X9.20, ZD4.A, ZD5.A, ZD6.A; also elsewhere on the board
IOEXP_DINP1: IC28.24 (GPA3), R58.2, ZD4.C
IOEXP_DINP2: IC28.25 (GPA4), R59.2, ZD5.C
IOEXP_DINP3: IC28.26 (GPA5), R60.2, ZD6.C
IOEXP_LED1: IC28.21 (GPA0), LED1.A
IOEXP_LED2: IC28.22 (GPA1), LED2.A
IOEXP_OCI1: IC28.1 (GPB0), OK2.8 (COL), R66.1
IOEXP_OCI2: IC28.2 (GPB1), OK2.6 (COL), R65.1
IOEXP_OCO1: IC28.27 (GPA6), R61.2
IOEXP_OCO2: IC28.28 (GPA7), R62.2
IPEXP_LED3: IC28.23 (GPA2), LED3.A
unnamed: OK2.4 (C), X8.13
unnamed: OK1.8 (COL), X8.10, ZD7.C
unnamed: OK1.7 (EMIT), X8.9, ZD7.A
unnamed: OK1.6 (COL), X8.8, ZD8.C
unnamed: OK1.5 (EMIT), X8.7, ZD8.A
unnamed: OK1.1 (A), R61.1
unnamed: D3.C, OK2.1 (A)
unnamed: OK2.2 (C), X8.11
unnamed: D3.A, R63.2
unnamed: IC27.1 (OSCI), Y1.1
unnamed: D4.A, R64.2
unnamed: D4.C, OK2.3 (A)
unnamed: R64.1, X8.14
unnamed: OK1.3 (A), R62.1
unnamed: R63.1, X8.12
unnamed: IC27.2 (OSCO), Y1.4 (2)
unnamed: LED1.C, R55.2
unnamed: LED2.C, R56.2
unnamed: LED3.C, R57.2
unnamed: R58.1, X8.1
unnamed: R59.1, X8.3
unnamed: R60.1, X8.5
unnamed: C79.1 (+), R54.1
unnamed: C78.2, D2.C, IC27.14 (VDD), R54.2
SPI1_CLK: IC26.11 (SRCLK), IC27.10 (SCL), IC28.12 (SCK), IC29.6 (SCK), J2.5 (CLK), MOD1.5 (SCLK); also elsewhere on the board
SPI1_MISO: IC27.8 (SDO), IC28.14 (SO), IC29.2 (SO), J2.7 (DAT0), MOD1.2 (MISO); also elsewhere on the board
SPI1_MOSI: IC26.14 (SER), IC27.9 (SDI), IC28.13 (SI), IC29.5 (SI), J2.3 (CMD), MOD1.3 (MOSI); also elsewhere on the board
SPI1_SELECT: IC26.12 (RCLK); also elsewhere on the board
SPI2_CLK: X9.3; also elsewhere on the board
SPI2_MISO: X9.4; also elsewhere on the board
SPI2_MOSI: X9.5; also elsewhere on the board
SPI2_SELECT: X9.6; also elsewhere on the board
SPI_INT: IC28.19 (INTB), IC28.20 (INTA); also elsewhere on the board
USB_ID: IC28.8 (GPB7); also elsewhere on the board
VBUS_EN: IC26.7 (Q7/H); also elsewhere on the board

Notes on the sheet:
Licensed under the TAPR Open Hardware License (www.tapr.org/OHL)
Repository: https://github.com/eez-open
More info at http://www.envox.hr/eez
SPI0 CS demux, EEPROM, Micro SD card, RTC
Riverdi LCD 20-pin connector (optional)
Real time clock with supercapacitor backup
W5500 Ethernet module (optional)
SPI#1 Chip select demultiplexer
I/O expander and interrupts collector
I/O Expander, W5500 Ethernet, Riverdi LCD
Micro SD card socket
EEPROM

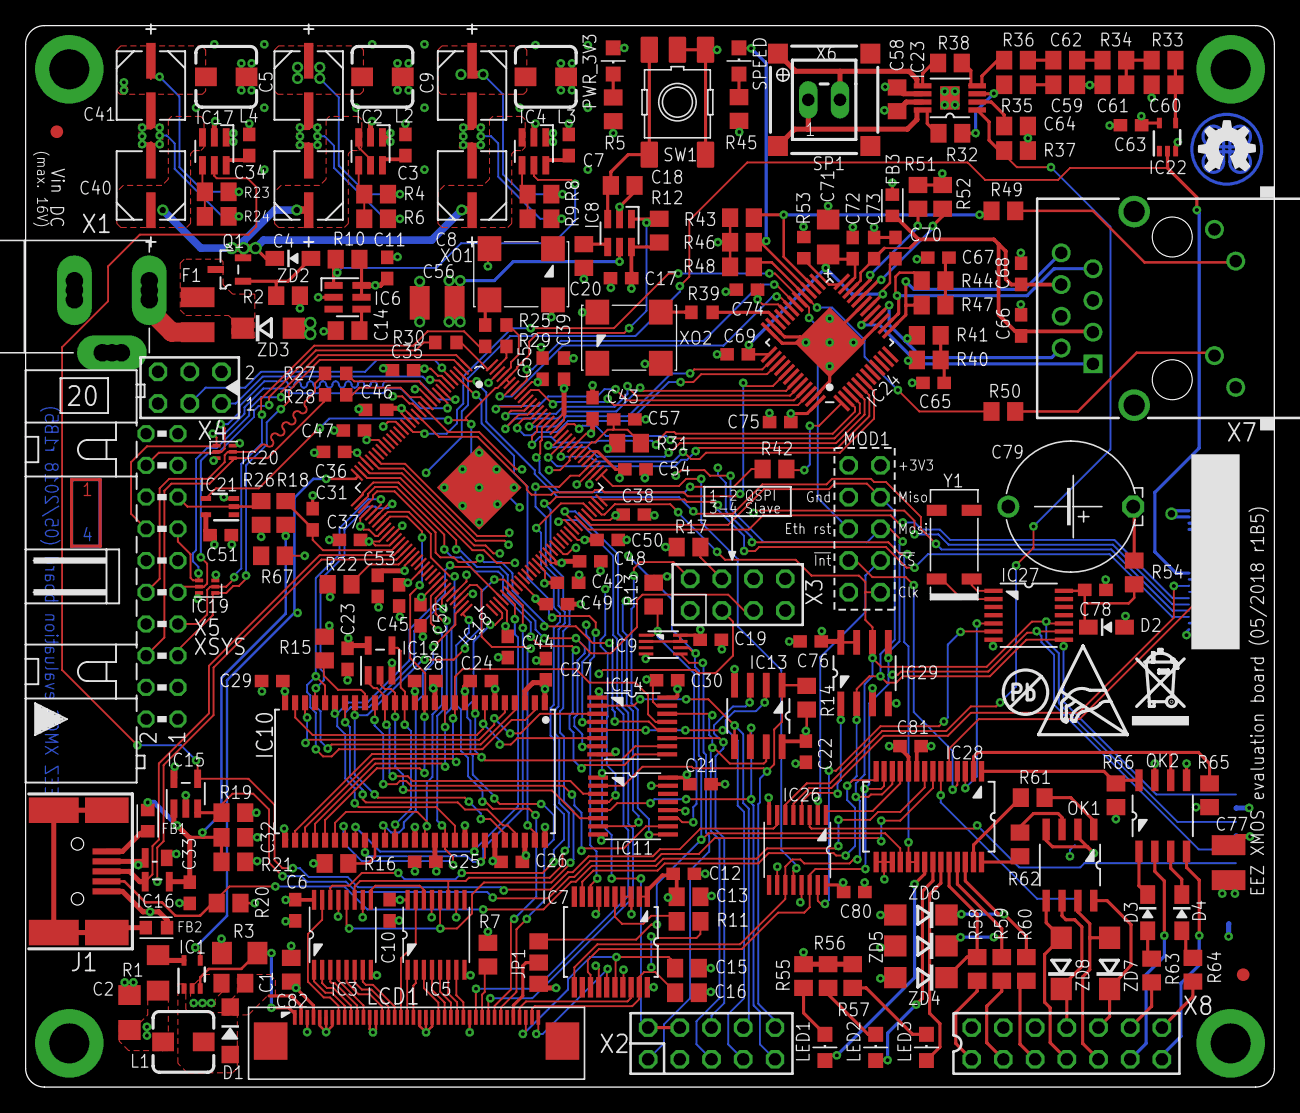
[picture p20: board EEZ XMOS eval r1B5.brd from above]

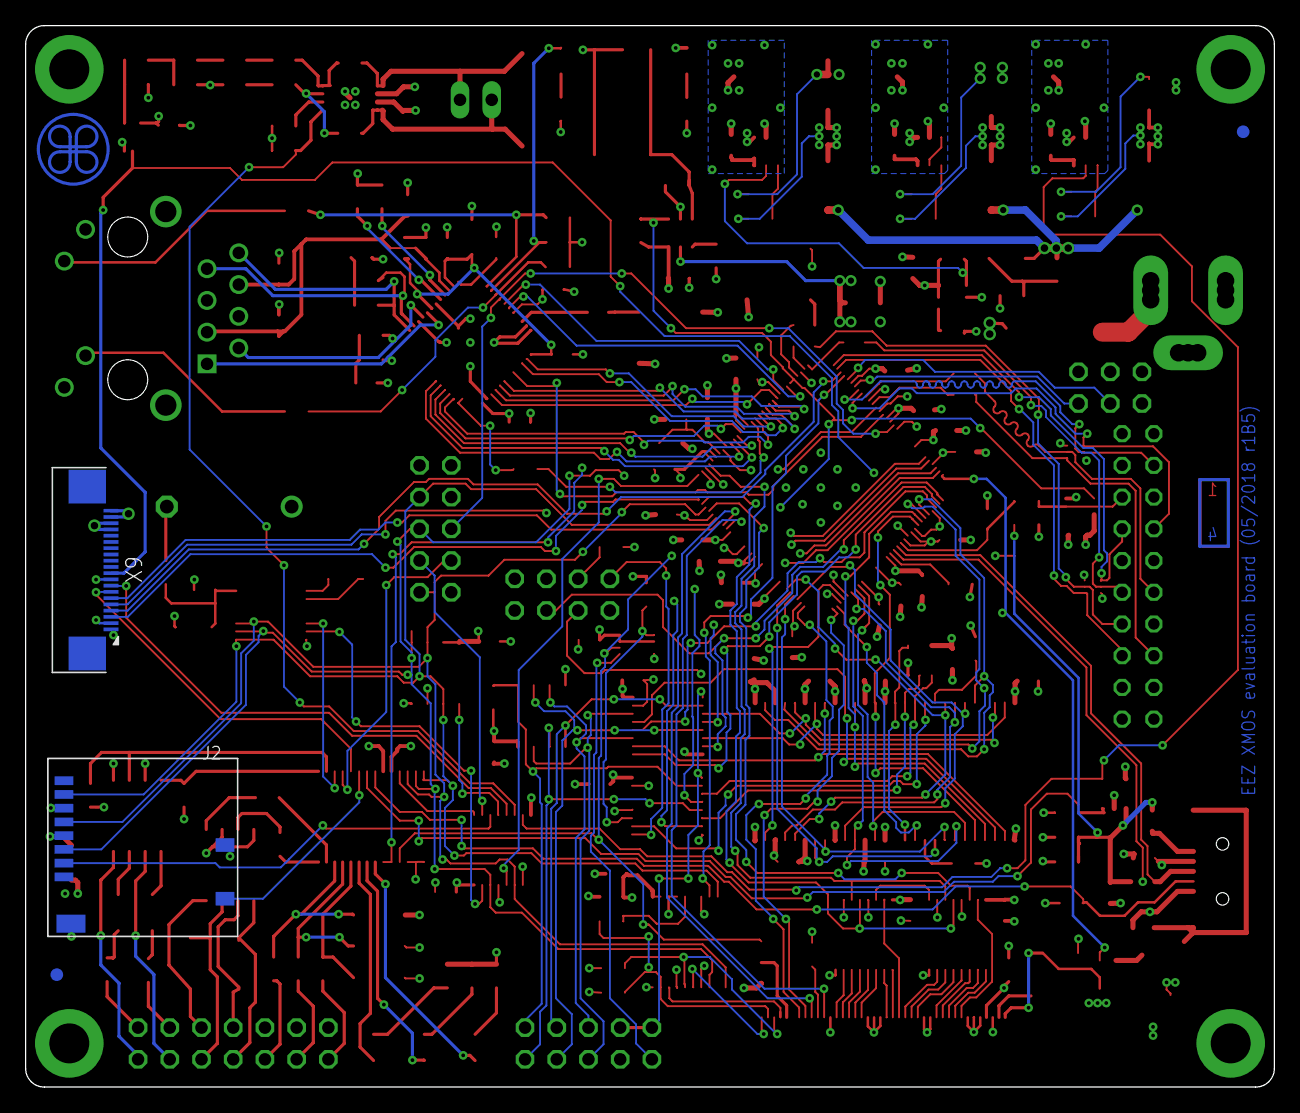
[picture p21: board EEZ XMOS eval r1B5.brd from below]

Board: 4 copper layers, 100.0 x 85.0 mm, 229 parts (3 on the bottom side), 231 nets.

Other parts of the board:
EEZ_SIGNATURE: SIGNATURESMALL; SIGNATURE_5MM
U$1: RECYCLE_BIN1/8
U$5: PB_SMALL
U$6: ESD_SYMBOL

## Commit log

2018-01-21 first commit, BOM is missing
    [EEZ XMOS eval r1B4.brd, EEZ XMOS eval r1B4.sch, XE216-512-TQ128 portmap for EEZ evaluation board r1B4.ods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]
2018-01-21 portmap filename change
    [XE216-512-TQ128_portmap_for_EEZ_evaluation_board_r1B4.ods]
2018-01-21 pin swap on X3
    [EEZ XMOS eval r1B4.brd, EEZ XMOS eval r1B4.sch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]
2018-01-22 BOM first version, added R67 as test point
    [EEZ XMOS eval r1B4 BOM.ods, EEZ XMOS eval r1B4.brd, EEZ XMOS eval r1B4.sch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]
2018-01-27 .brd file optimization
    [EEZ XMOS eval r1B4.brd, EEZ XMOS eval r1B4.sch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]
2018-02-24 #1, #2
    [EEZ XMOS eval r1B4 BOM.ods, EEZ XMOS eval r1B5 BOM.ods, EEZ XMOS eval r1B5.brd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]
2018-03-07 fixed flash memory model
    [EEZ XMOS eval r1B5 BOM.ods, EEZ XMOS eval r1B5.brd, EEZ XMOS eval r1B5.sch]
2018-05-03 better placement of SD card capacitor (C77)
    [EEZ XMOS eval r1B5.brd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]
